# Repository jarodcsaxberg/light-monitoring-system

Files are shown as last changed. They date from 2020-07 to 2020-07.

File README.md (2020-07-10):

# Light Monitoring System

This project seeks to design a light sensor that can be placed in the Hoosier National Forest for a prolonged period of time. The sensor will collect data on the light conditions during the night to obtain an official designation from the International Dark Sky Association (ISDA) for the Hoosier National Forest. The designation is important to attract more visitors to the Forest, to create community-involved programs regarding data collection from the sensors, and to teach people about what the IDSA association strives to do and why it is important.

## Project Code

The code can be found in [project/](https://github.com/jarodcsaxberg/light-monitoring-system/tree/master/project), with the custom written code found in [project/Inc](https://github.com/jarodcsaxberg/light-monitoring-system/tree/master/project/Inc) and [project/Src](https://github.com/jarodcsaxberg/light-monitoring-system/tree/master/project/Src).

## Design

The KiCad files for the PCB design can be found in [kicad_proj/e314_light_sensor](https://github.com/jarodcsaxberg/light-monitoring-system/tree/master/kicad_proj/e314_light_sensor).

A KiCad schematic is located [here](https://github.com/jarodcsaxberg/light-monitoring-system/blob/master/design_analysis/schematic.pdf).

The Fusion 360 files for the enclosure design can be found in [enclosure/](https://github.com/jarodcsaxberg/light-monitoring-system/tree/master/enclosure).

## Analysis

Cost and power analysis for the project is located in [cost_power_analysis/](https://github.com/jarodcsaxberg/light-monitoring-system/tree/master/cost_power_analysis).

Design analysis can be found in [design_analysis/](https://github.com/jarodcsaxberg/light-monitoring-system/tree/master/design_analysis).

## Final Report

The final report can be found in [final_report/](https://github.com/jarodcsaxberg/light-monitoring-system/tree/master/final_report).

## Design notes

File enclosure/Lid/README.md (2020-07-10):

# Lab 9 - Lid
Completed in Fusion 360. Included dxf file for laser cutting.

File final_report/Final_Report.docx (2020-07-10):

Indiana University Engineering

Final Document

Team: Jarod Saxberg, Tyler Zhang

Project: Light Monitoring System

Date: 5/4/2020

# 1 Table of Contents

# 2 System Executive Summary

## 2.1 Description of the Community Partner

The project partner for this project is the Hoosier National Forest. The Hoosier National Forest’s goal is to achieve Dark Skies designation from the International Dark Skies Association (IDA) for its land before the next solar eclipse in 2024. Should they gain this designation, the Hoosier National Forest will benefit immensely from increased eco-tourism. Additionally, the data collected for the project will benefit wildlife and scientists that need the dark sky. The Hoosier National Forest will be the first to receive the project deliverables.

## 2.2 Stakeholders

If the project is particularly successful, the IDA may also use our project to assist assigning Dark Sky designation in other locations. Additionally, Professor Himebaugh is significantly interested in the project’s success, as he is concurrently working on similar projects for his research.

## 2.3 Project Objectives

The current method of collecting light data is by sending a ranger out with a handheld light sensor and manually collecting light data. Collecting light data is labor-intensive and costly, and as a result light data is collected infrequently. Our project aims to provide light data every five minutes, which will provide significant improvement over the current light data collection system. Precise light data is a direct requirement for Dark Sky designation, and the data from our project will be used by the IDA to consider Hoosier National Forest for a Dark Skies designation. Additionally, more frequent light data will allow the Hoosier National Forest to study the impact of dark skies on the wildlife.

## 2.4 Outcomes/Deliverables

Our goal is to produce a light monitoring system that improves upon the current light data collection system. Our system will be automated and can collect data more frequently because it will be deployed in the forest. Additionally, we will improve the current prototypes of the light monitoring system with a combination of more efficient code and better hardware. When the project is complete, we hope to leave behind light data and an improved prototype for the system.

# 3 System Description

This project seeks to design a light sensor that can be laid in the Hoosier National Forest for a prolonged period of time. The sensor will collect data on the light conditions during the night in an attempt to obtain a designation from the International Dark Sky Association. The designation is important to attract more people to the Forest, to create community-involved programs regarding data collection from the sensors, and to teach people about what the IDSA association strives to do and why it is important.

The light sensor is designed by taking many different considerations into account. These considerations involve safety, cost, and ethics, and they are all described in more detail later in the document. The software is designed with the help of CubeMX, which provides an extremely helpful starting point for the coding of each feature and includes utilities that help establish timers and explore various power consumption modes. The hardware was designed with KiCad, a user-friendly way to design schematics and pcb layouts. KiCad allows the user to have full control over the lithography of the resulting pcb, and performs electrical rules checking in the schematic to reassure the user that all connections are established. Creating a pcb with KiCad gives the designers more control over the board rather than purchasing a prebuilt board which could have features that are not necessary. More detailed descriptions of the software and hardware design are immediately following this section.

# 4 Software Design

## 4.1 High Level Block Design

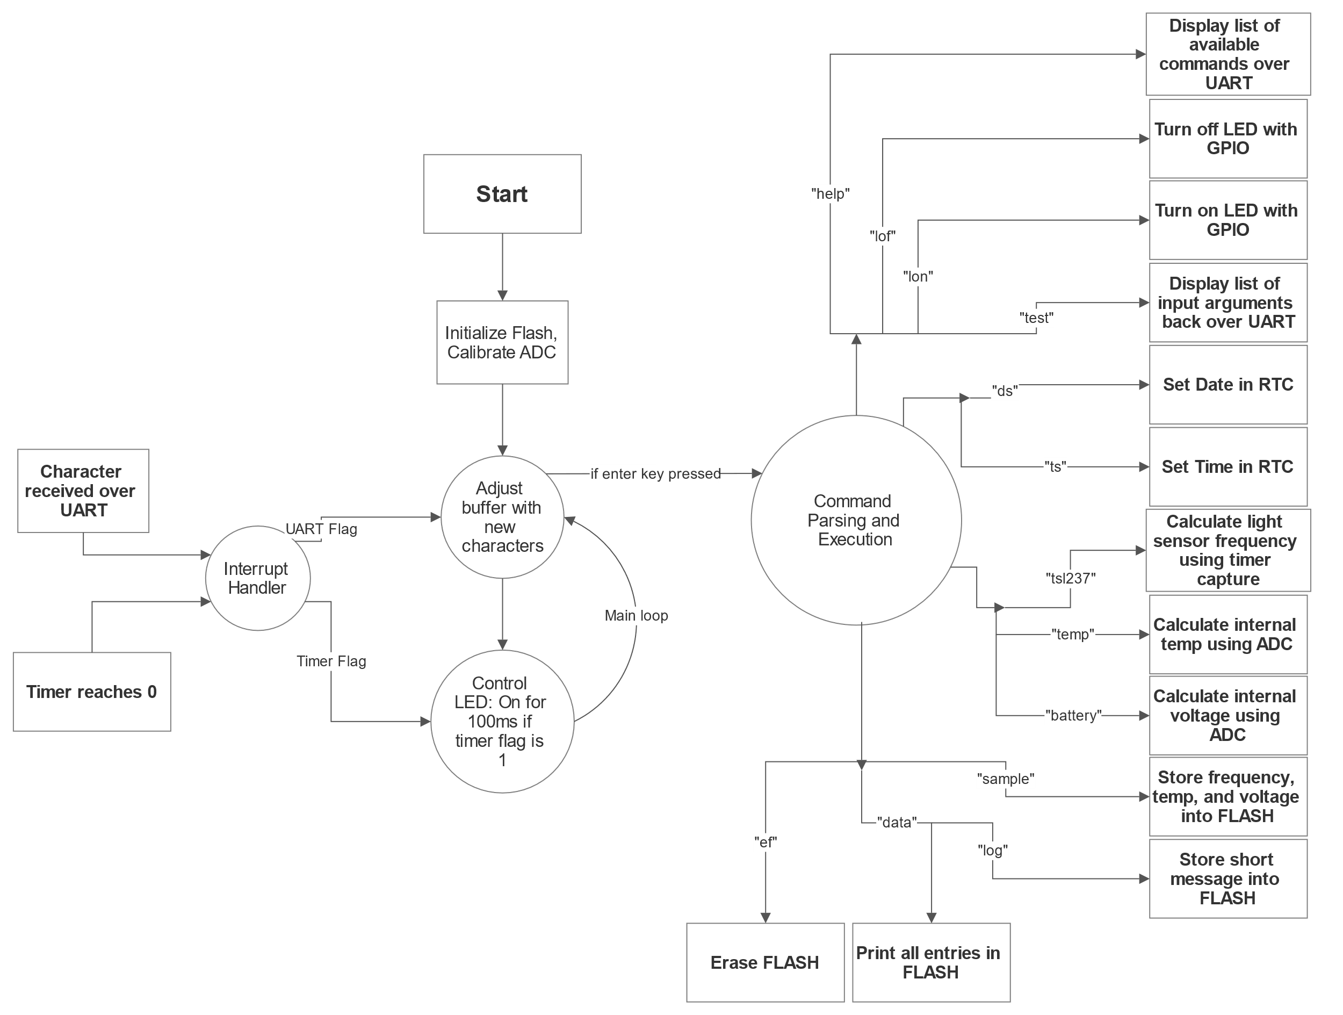
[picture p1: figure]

Figure 1: Software block design

Figure 1 shows the flow of our code. The code is mainly event-driven since the main loop waits for input over UART or for the timer to reach 0. Receiving characters over UART modifies an internal buffer, and if the enter key is detected, the system will perform a command. If the connected timer reaches 0, the code will tell an LED to blink on for 100ms. This behavior will eventually be replaced by storing a light sensor reading to flash memory.

## 4.2 Power Management and Modeling

The STM provides several run and low-power modes, each with different features and power consumption. Our goal is to leave the system in the field while requiring as little maintenance as possible. The system is designed to take light samples every 15 minutes for 12 hours a day, with each sample taking up to 15 seconds. When the system is taking a light sample, the STM will be in one of three running modes, and while it is idle, the system will be in one of seven low-power modes.

The following graphs show the power consumption of three promising combinations of run and low-power modes, generated by CubeMX. The rest of the combinations were tested in our full power analysis, which can be located here (https://github.iu.edu/jsaxberg/ES-SPRING-2020/blob/master/Lab10/e314_power_analysis_final.pdf). We are trying to determine the pair of run and low-power modes that will yield the best battery life estimation with a CR2032 battery.

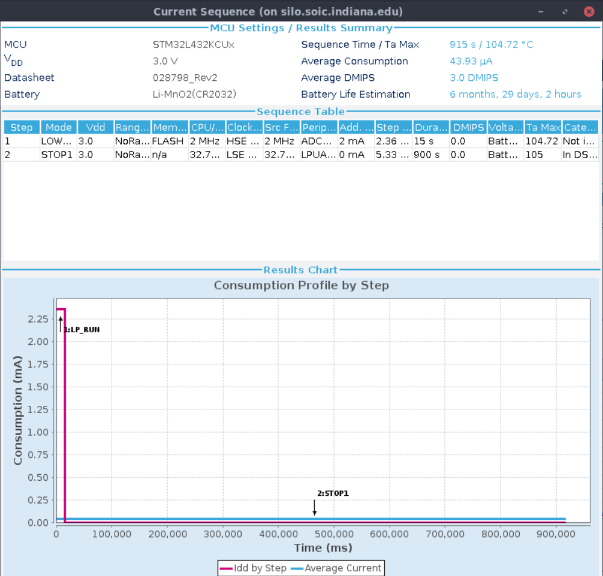
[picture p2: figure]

Figure 2: LPRUN with STOP 1

With these settings, battery life is at nearly 7 months and its wakeup time is 4 us. The LPUART and RTC can still be enabled, and SRAM is retained. These settings give us the best battery life estimation, but the LPRUN only allows the CPU to run at a maximum of 2 MHz, which may not be enough for the software.

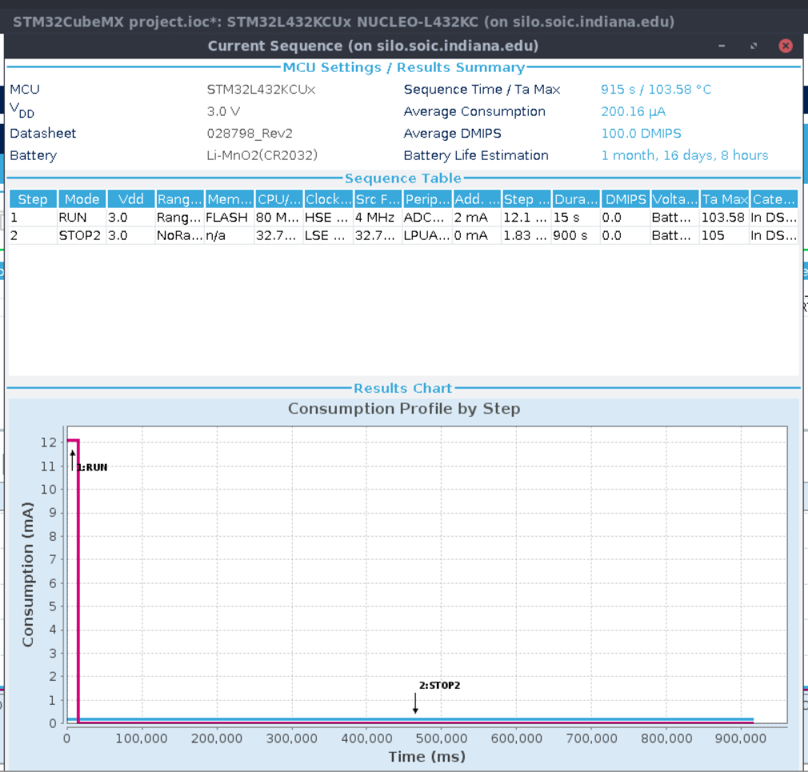
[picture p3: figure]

Figure 3: RUN1 with STOP 2

With these settings, battery life is at roughly 1.5 months and its wakeup time is 5 us. The LPUART and RTC can still be enabled, and SRAM is retained. However, RUN1 means the CPU is running at 80 MHz, which is unnecessary and draws significantly more power than LPRUN or RUN2.

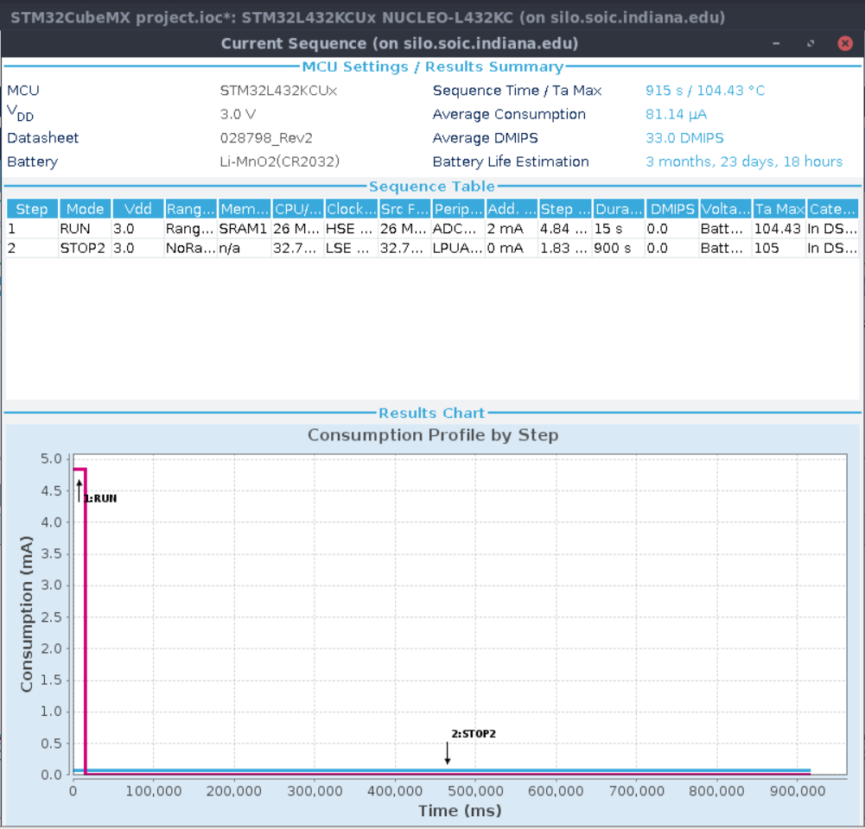
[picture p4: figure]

Figure 4: RUN2 with STOP 2

With these settings, battery life is at 3 months and 25 days and its wakeup time is 5 us. The LPUART and RTC can still be enabled, and SRAM is retained. RUN2 lets caps the CPU frequency at 26 MHz instead of 80 MHz, showing power consumption improvements.

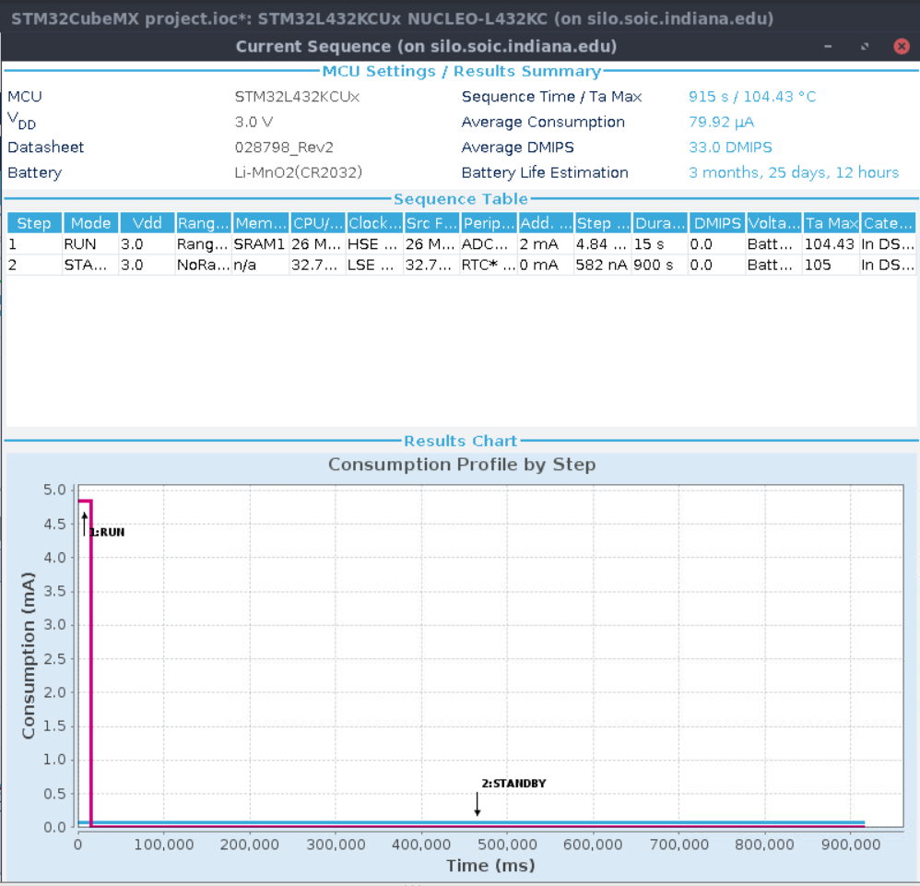
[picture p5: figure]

Figure 5: RUN2 with STANDBY + 32KB SRAM

With these settings, battery life is at 3 months and 25 days and its wakeup time is quite high at 14 us. The LPUART can no longer stay enabled, but RTC is still active and SRAM is retained. This means if we want to communicate with the device over UART, we must wait for the 15 second window when the system is back in the run mode.

The power combination that provides the best battery life for the least detrimental effects is RUN2 with STOP 2. The CPU runs at a max of 26 MHz which should be plenty for our code. STOP 2 allows the LPUART to remain on, allowing us to communicate with the device without waiting. It also has decent battery life estimation at 3 months and 23 days.

# 5 Hardware Design

## 5.1 Overview

KiCad was used to create a schematic and pcb layout for the light sensor project. In the design of the hardware, we needed to account for all components included on the board and manage the lithography so everything connects how it should. The design we determined was the best is shown below.

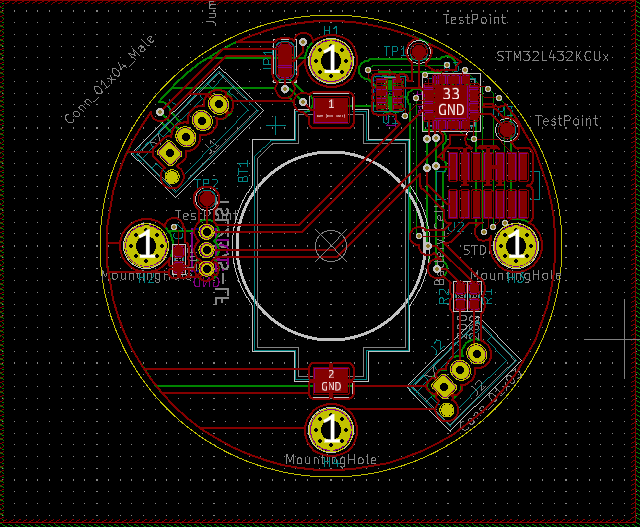
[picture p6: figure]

On the design, the red outlines represent lithography done on the top of the board, and the green represents the bottom. A more detailed explanation of certain important parts are included in the next section.

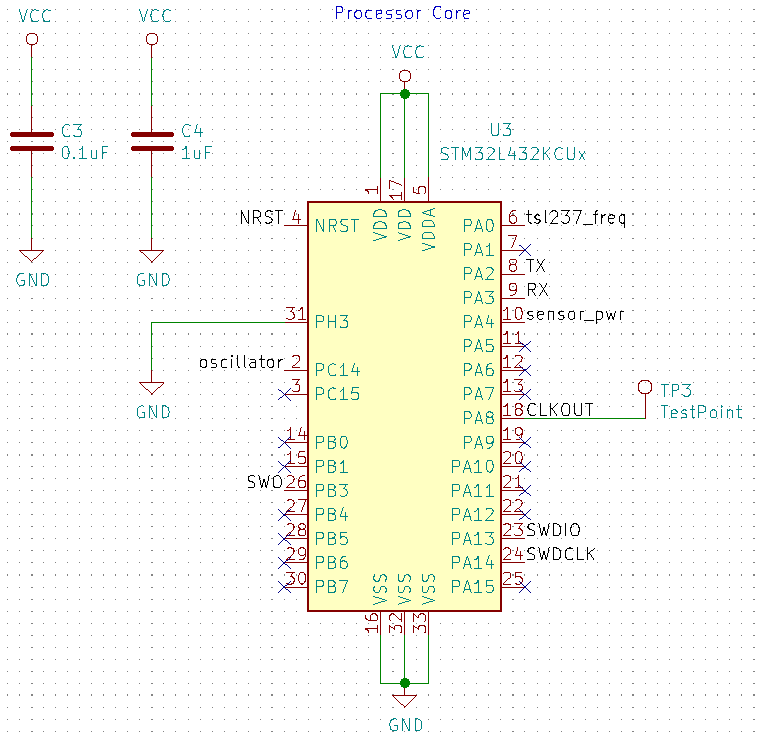
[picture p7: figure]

## 5.2 Processor Core

The processor used in the hardware is the STM32L432. This was chosen for its extensive number of timers and general support for the goals of this project. It is only somewhat limited in flash space, as there are other processors out there that have twice the storage space. The test point is to watch the system clock to use in reference with the other test points.

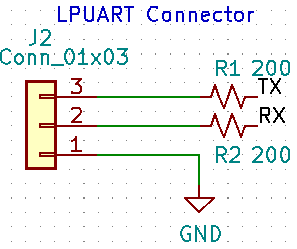
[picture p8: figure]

## 5.3 LPUART Connector

The LPUART connector is important as it allows for data to be received from the flash memory of the processor.

## 5.4 Light Sensor

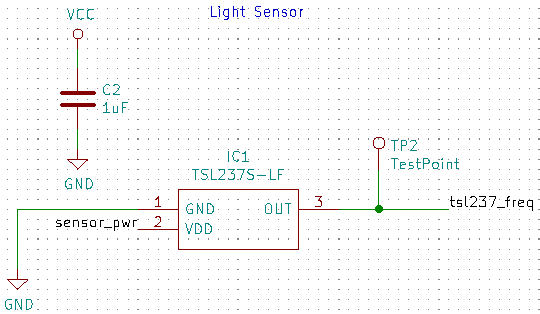
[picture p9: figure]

The light sensor is arguably the most important part of this project, as it is the key feature of it. The TSL237S light sensor was picked for the project, and the values it outputs from its readings are in terms of Hz which are processed in the software. The test point is to probe the output frequency.

## 5.5 Oscillator

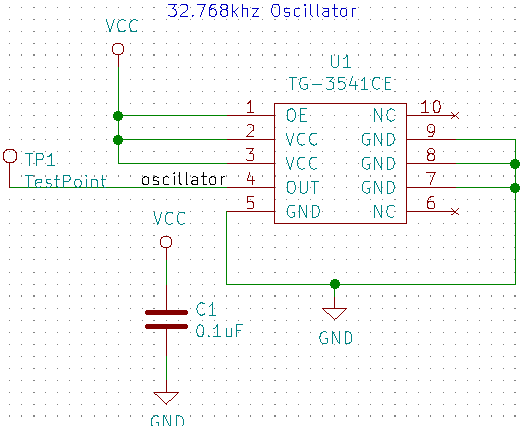
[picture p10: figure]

The oscillator is used to control the clock of the system. The test point is useful to see that the system is oscillating correctly.

# 6 Enclosure Design

## 6.1 Description of the Enclosure Design

The enclosure for our PCB is designed to be durable and protect the electronics from moisture. The figures below show the 3D models for our base and lid. The base will be 3D printed and the lid will be laser-cut from acrylic.

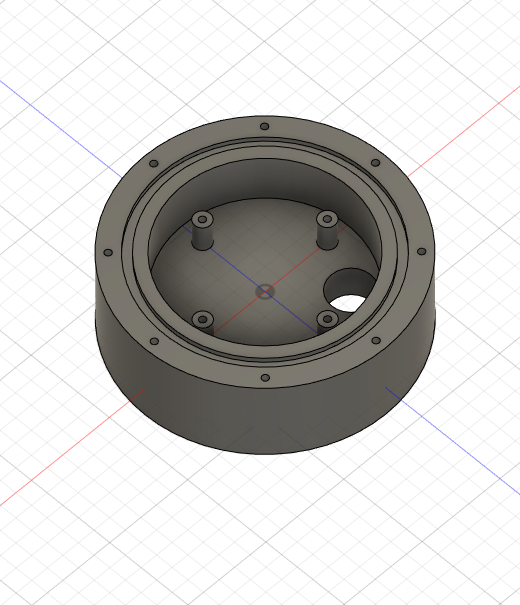
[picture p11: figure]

Figure 6: Base design, modeled in Autodesk Fusion

The base has standoffs to mount the PCB, and screw holes to secure the lid. The standoffs provide space between the PCB and the bottom of the base for the battery holder. The space can be used to store desiccant beads to reduce moisture in the enclosure. A cutout at the bottom of the base provides easy access to the LPUART connector, and will be filled in with a rubber plug.

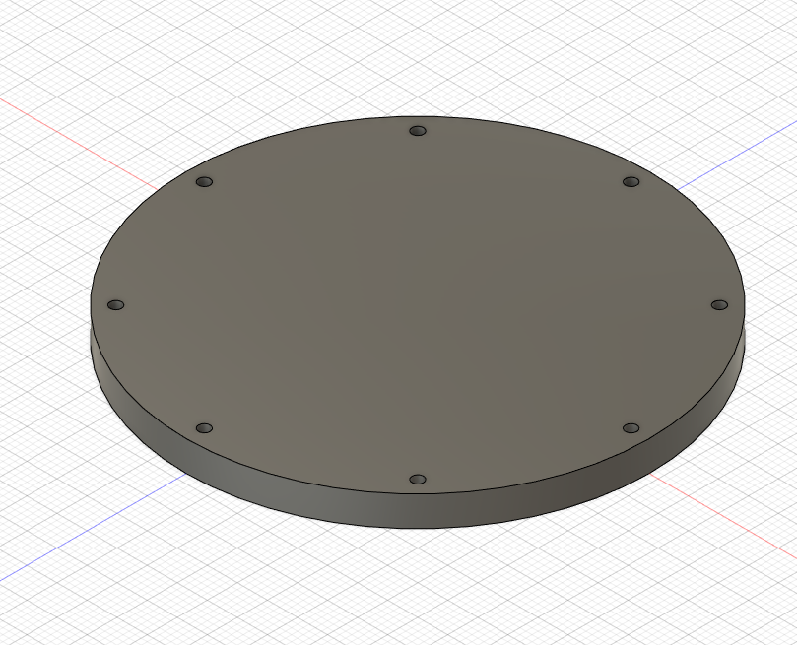
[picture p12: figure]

Figure 7: Lid design, modeled in Autodesk Fusion

The light sensor will be facing outwards, so the lid must be laser cut from clear acrylic to maintain accurate light readings. Between the lid and the base, there is a groove for the placement of a rubber O-ring to seal the enclosure.

## 6.2 NEMA Enclosure Level

The National Electrical Manufacturers Association provides standards for enclosures in indoor and outdoor locations. For our light monitoring system, our environment will be the Hoosier National Forest, which is considered an outdoor nonhazardous location. The following figure shows the NEMA classification levels for an enclosure in such an environment.

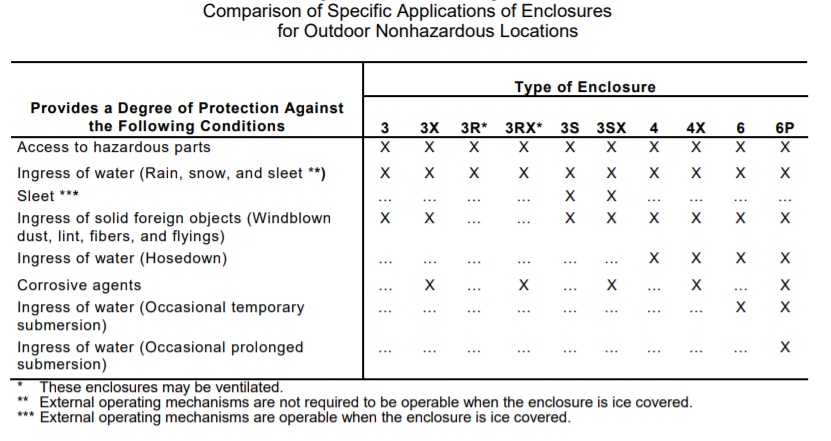
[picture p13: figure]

Figure 8: NEMA classification for enclosures in outdoor nonhazardous locations

All the electronics are secured inside the enclosure, so access to hazardous parts is limited. The design protects the electronics from windblown dust, lint, fibers, and flyings. Additionally, with the O-ring seal and the rubber plug, the electronics are protected against ingress of water from rain, snow, and sleet. Ice formation may shut down the electronics, but the enclosure will be intact, and the screws may still be removed. The enclosure is not well-sealed enough to protect against hose downs or any type of submersion. Additionally, corrosive agents may interact negatively with the acrylic and ABS material in our enclosure. With these degrees of protection, the classification of our enclosure type matches Type 3S.

# 7 System Cost Modeling

Background

For the design, we made sure to account for all mounting necessary. The four holes inside are ready for screws that mount the PCB to the base. The base will be 3D printed with a basic plastic material. It does not have to be anything more as plastic will last a while in basic outdoors conditions. The lid will be laser cut from clear acrylic. It must be clear to allow light through for the light sensor. All of the smaller holes in the lid and base are used for connecting the two and including some type of material to seal the two together, whether it be an o-ring or some type of glue. The PCB layout is the same layout that was designed in Lab 8.

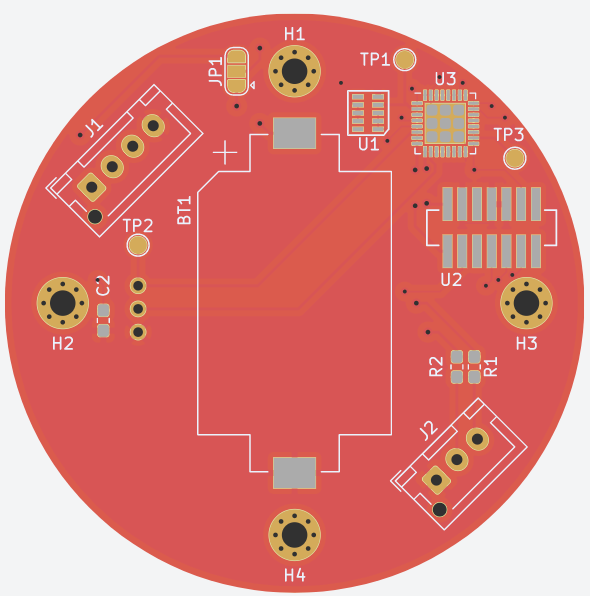
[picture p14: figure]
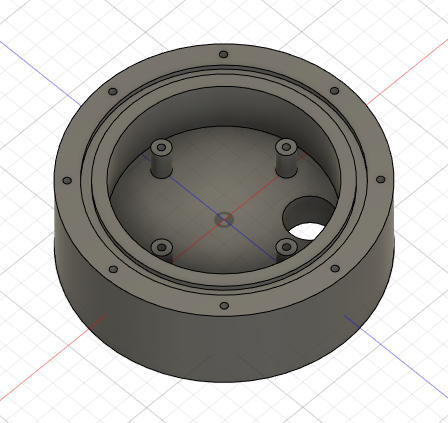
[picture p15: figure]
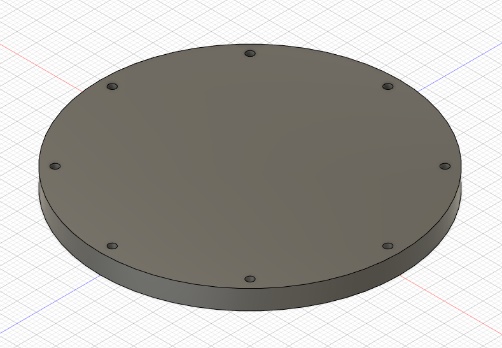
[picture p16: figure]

Cost Analysis

Sculpteo

| 5 | 20 | 50 | 100
Base | $355.60 | $1,890.00 | $4,725.00 | $9,450.00
Lid | $14.35 | $40.00 | $92.50 | $180.00
Total | $369.95 | $1,930.00 | $4,817.50 | $9,630.00

Shapeways (not including 15% edu discount) (prices for 3D printing only)

| 5 | 20 | 50 | 100
Base | $251.95 | $1,007.80 | $2,519.50 | $5,039.00
Lid | $78.90 | $315.60 | $789.00 | $1,578.00
Total | $330.85 | $1,323.40 | $3,308.50 | $6,617.00

Macrofab

| 5 | 20 | 50 | 100
PCB | $143.77 | $532.55 | $834.45 | $1,092.39

The above tables show prices to obtain each part from the different companies that offer 3D printing, laser cutting, and PCB printing services. For each company, I chose the most cost-effective solution which involved prioritizing cost over speed. For most of the companies, it would take around 2-4 weeks to receive the components ordered. Speed is not as important of a factor when we are trying to make sure the boards are as low-priced as possible.

Conclusion

Based on the various prices, the best and cheapest way to obtain the base + lid combo would be to use Sculpteo for the lid, Shapeways for the base, and Macrofab for the PCB. The price for Shapeways would also be reduced by taking advantage of the 15% education discount, which was not included in the above graphs. Adding this sum up, with the education discount included, the total for 100 light sensors would be $5,555.54; thus, the price per unit would be $55.55.

# 8 Safety Considerations

This section is a consideration of various possible failure modes and their effects on the system and its environment.

- Obstruction of acrylic lid

Any obstruction such as leaves or debris that block the acrylic lid of the enclosure will also block the light sensor, making sensor readings useless. This will likely be a very common occurrence, especially in the fall. Unfortunately, without any mechanism to clear debris, the device will be stuck in this state until a human or some entity clears away the obstruction.

To detect obstructions, we may add some code to check whether our light sensor data makes sense at the given time. For instance, if the system detects darkness during the middle of the day, it could log that an obstruction has been detected, and we can program the system to stop collecting data to preserve battery life.

- Battery reaches end of life prematurely

The battery life might be exhausted earlier than predicted due to battery manufacturing errors. Another possibility is that we accidentally programmed the system to stay in running mode instead of switching to low power while idle. When the battery dies, the only rescue is for a human to load the data logs from FLASH and reset the device, since losing battery power prevents the system from logging any more data. However, since our logs should display battery voltage with a timestamp, we can figure out at what time we lost power and attempt to debug our issue.

- Defective battery connection (short)

If the battery holder is defective, it may create a short circuit between the leads of the battery. This is quite dangerous as the battery will heat up and potentially cause a small explosion. If this happens inside the enclosure, the hazard will be isolated and will damage the electronics. The coating on the PCB will prevent any fires from starting. However, it is very likely that the short would be caught before the PCB even makes it into the enclosure, because the process happens very quickly once the battery is in place. This failure mode would endanger anyone nearby as well as damage the other electronics on the PCB.

- Faulty peripherals

Faulty peripherals on the STM such as the ADC or the RTC or problems with the TSL237 will make the data collected useless. We would need to replace the microcontroller or sensor. Fortunately, this is usually caught by quality assurance during manufacturing, so it is unlikely to become our issue. Additionally, if it happens, it is easy enough to check that the peripherals are working before deploying the system.

- Rubber plug comes loose

In our enclosure design, there is a removable rubber plug on the bottom of the base that allows us to access the UART connector. If this plug is loose or removed, it will expose the electronics to the environment, and may allow moisture or water to get inside. Moisture could potentially short or damage the electronics and ruin the collected data. Additionally, if for any reason a fire starts inside the enclosure, the fire will be exposed to the forest if the rubber plug is missing. We must make sure that the plug is properly sealing the hole before deploying the system.

- Extreme temperature conditions

With our device outdoors, the system is at the mercy of the elements. The STM and TSL237 function at a relatively wide range of temperatures, but at the extremes, unpredictable behavior can occur. At extremely low temperatures, the battery will not be able to generate enough current, which may shut off the RTC, making future timestamps inaccurate. At extremely high temperatures, the battery will overheat and may catch fire. We must be sure the Hoosier National Forest has temperature ranges that fall within the operating temperature range of our system.

- Tampering from tourists

Tourists may be curious about the device if spotted in the forest. They may try to examine the electronics by opening the interior or steal the device. This may affect data quality or cause damage if handled improperly. The closer we deploy the device to a well-travelled path, the more likely we will encounter tourists. We can potentially reduce tampering by letting visitors know what the devices are doing so they do not interfere.

# 9 Ethical Considerations

This section will detail all the various ethical considerations that were considered over the course of the project.

- Mounting the sensor to the ground

The grounds of the Hoosier National Forest are protected, and due to these protections, no stakes can be inserted into the ground. To account for this, we must have some way of weighing the sensors down, so they do not get moved by wind or animals. There is only so much we can do to account for this, and the best way to do so is to add some weight to the bottom of the enclosure.

- Damage to animal and insect ecosystems

The light sensor could possibly interfere with insects on the ground. We attempt to reduce this impact by placing the sensors far apart from one another and keeping the radius of the sensor and enclosure small.

- Potential hazardous waste if the sensors are forgotten

If the light sensors are damaged or moved, it may be difficult to retrieve them from the Forest. The forgotten sensors would be left in the Forest until they happen to be found, or they decompose. The sensors are plastic and metal, both of which take a while to decompose. The battery of the system and the components on the pcb also have toxic materials within them, and they have the potential to release these into the environment. We mitigate this by noting the locations of all the sensors when they are planted and including some form of camouflage to the design to reduce the chance they are found by external people or animals.

- Increased park traffic will negatively affect the animals

If the project goes to plan, part of it is trying to attract more people to the Forest. This could negatively affect the natural life there and impact animal habitats. We believe that the increased awareness that this project will bring is of greater importance. The Forest is very large and widespread. An increase of people at the park will not have as great of an effect on the overall park, and while they are there, they will learn about the Dark Sky endeavor and why it is done. This has the potential to affect life outside the park too. If someone learns about the initiative at the park, then goes home and changes their driveway light to a Dark Sky recommended light, it will benefit more than just the park. These people also have the potential to spread the information through work of mouth, further increasing the affect of the community involvement project.

# 10 Future Work

There are several ways to improve the light monitoring system, both in terms of design and software.

## 10.1 Improvements to Software

Currently the software in our system is run in “bare-metal” (i.e. tasks execute one at a time and not concurrently). One improvement is to utilize a real-time operating system (RTOS) to gain access to multiple threads and run tasks concurrently. This would be beneficial for tasks that require any sort of polling, such as calculating frequency, which currently is done by polling an input capture timer for two readings. During that time, the main loop is stopped, which could potentially be long enough to miss important interrupts from UART or other timers. The function printf also has similar behavior, as it calls a function called putchar that also waits for the UART module to receive before returning. Placing command execution and interrupt processing into separate threads or tasks with an RTOS will make the code more robust.

## 10.2 Improvements to Hardware

The light monitoring system currently runs on a button battery, but a possible improvement to extend battery life is to add a solar cell to the system. The solar cell could charge a capacitor during the day and the system could use the capacitor as well as a backup battery during the night to record data. Solar power could make the system sustainable and reduce the number of times we need to replace the battery.

Another addition would be providing adding a Bluetooth module to the system to let users download data from the system without needing to connect with UART. Not only is this more convenient, but also it allows us to take advantage of citizen science by allowing visitors at the Hoosier National Forest collect data for us. We could build an app for visitors to download and let them use the Bluetooth receivers in their phones to retrieve data from our systems. The app could then send us the data when the phone connects to the internet. This would greatly improve the efficiency of data collection for the Hoosier National Forest.

# 11 Team

## 11.1 Team Members

### 11.1.1 Jarod Saxberg

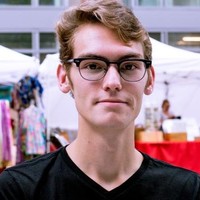
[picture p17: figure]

Jarod is a junior at Indiana University pursuing a major in Intelligent Systems Engineering concentrating in Computer Engineering, and two minors in Mathematics and French. He will be working over the summer of 2020 as a security software engineering intern and plans to either continue with a career in cyber security, or work at the intersection of hardware and software.

### 11.1.2 Tyler Zhang

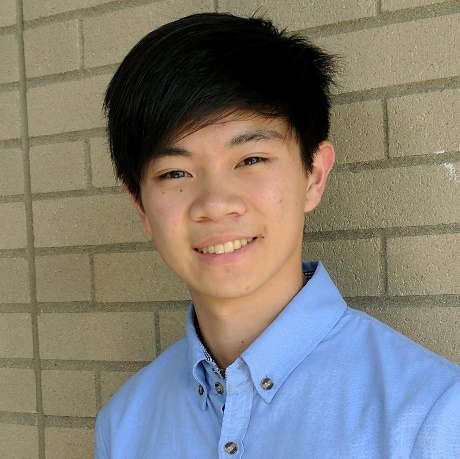
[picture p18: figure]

Tyler is a student at Indiana University pursuing a double degree in Mathematics and Intelligent Systems Engineering, with a concentration in Cyber-Physical Systems. Future career goals include obtaining a master’s degree in engineering and working in the field of embedded systems.

## 11.2 Workload

Both individuals contributed significantly to the design and documentation of the project, including the code, the PCB layout, and the enclosure model. The following is the breakdown of specific contributions.

### 11.2.1 Jarod Saxberg

- Both members worked extensively on the code, and focused on the software more than the hardware. One of them would usually get a good start on the code for a lab, then they would get together and work out any bugs and/or finish work that was not started yet. Most progress was made while working together.
- Jarod designed a PCB layout and enclosure model, along with Tyler creating his own too.
- Jarod completed the system cost analysis and was responsible for the odd-numbered sections of the final report. The Bill of Materials was split in half with each member working on their half.

### 11.2.2 Tyler Zhang

- Both individuals contributed significantly to the code. Typically, Tyler would provide a strong starting point for the labs by laying out the framework and structure, setting up functions, creating new files, and experimenting with how best to interact with the hardware and peripherals.
- Tyler designed his own PCB layout and enclosure model, as did Jarod.
- In terms of documentation, Tyler completed the power analysis and is responsible for the even-numbered sections in the final report. Both individuals picked parts for the bill of materials.

# 12 References

- NEMA Enclosure Types, NEMA 250-2013, Nov. 2005. [Online]. Available: https://www.nema.org/Products/Documents/nema-enclosure-types.pdf
- International Dark Sky Places, IDA [Online]. Available: https://www.darksky.org/our-work/conservation/idsp/

Last revised 05/04/2020 15

Final Document Team: Jarod & Tyler, Project: Light Monitoring System

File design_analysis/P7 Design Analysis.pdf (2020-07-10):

Saxberg and Zhang 1

Design Analysis

Summary:
We consider three microcontroller alternatives to the STM32L432KC (STM). The first is the MSP430F5359, which boasts efficient low-power modes and access to more memory and GPIO pins. The second is the ADuCM4050, which includes more memory and some security features. The third is the MAX32625, which has access to more memory, an extremely low power mode, and faster clock speed.

Alternative 1:
MSP430F5359 (http://www.ti.com/product/MSP430F5359)
http://www.ti.com/lit/ds/symlink/msp430f5359.pdf
The MSP430F5359 (MSP) is a low-power MCU from Texas Instruments, with specifications that are comparable with the STM. The operating voltage for the MSP falls between 1.8V and 3.6V, which is similar to that of the STM. Both chips have dedicated 32 kHz oscillators for the RTC, a 12-bit ADC channel, access to general-purpose timers, and UART support. Both chips utilize a similar amount of SRAM, with the MSP using 66 kB while the STM uses 64 kB.
A benefit of using the MSP is that it has multiple efficient low-power modes, with most of its low-power modes consuming less than 4 uA of current per MHz. The only time the STM achieves this type of power efficiency is when it is in one of its stop modes. The MSP also has 74 GPIO pins compared to the STM’s 26 pins, 64 priority levels for its interrupt handler compared to STM’s 16 levels, and 512 kB of flash memory compared to the STM’s 256 kB. Although the MSP seems to have higher specifications than the MSP, in practice we do not need the additional GPIO pins, priority levels, and flash, since we do not use all of the ones available on the STM.
A significant drawback is that the MSP uses a 16-bit RISC core instead of a 32-bit ARM core. As a result, it will be tough to implement floating-point operations, but it does have dedicated hardware for 32-bit integer operations. For 1000 units, the MSP is also more expensive, as it costs around $4.50 for the MSP on the Texas Instruments website. The STM only costs $2.43 from Digikey.

Alternative 2:
ADuCM4050 (https://www.analog.com/en/products/aducm4050.html)
https://www.analog.com/media/en/technical-documentation/data-sheets/ADuCM4050.pdf
The ADuCM4050 is an ARM Cortex-M4F based microcontroller from Analog Devices. The specifications are similar to the STM, but there are a few differences that make it better in some regards, and worse in others. Both chips have similar power supply voltages, 1.74V-3.6V for the ADuCM and 1.71V-3.6V for the STM. They also both have hibernate/sleep modes, which is necessary for our long term use of the light sensor. The clock in both chips is controlled by a 32 kHz crystal oscillator clock. The temperature range for both microcontrollers is similar, -40C to 85C, however the data sheet for the STM says the upper range can be 85/105/125C.

Saxberg and Zhang 2

The ADuCM chip only has three general purpose timers compared to the STM chip’s 11 varied timers. It also lacks in communication interfaces, only having 7 serial communication ports compared to the STM’s 14. Cost-wise, the ADuCM chip is much more expensive, currently priced at $10.29 per unit when buying 1000+, whereas the STM retails for $2.43.
Some advantages of the ADuCM chip are detailed below. The flash memory size is much larger, 512 kB versus 256 kB. This would allow for more storage of light sensor data and less time spent having to retrieve the data. The ADuCM chip also has 72 pins compared to the STM’s 26. If necessary, the ADuCM chip also has a hardware cryptographic accelerator which supports 3 different types of cryptographic functions, which could be used to protect our data from anyone who may steal the chip while it is deployed.

Alternative 3:
MAX32625 (https://www.maximintegrated.com/en/products/microcontrollers/MAX32625.html)
https://datasheets.maximintegrated.com/en/ds/MAX32625-MAX32626.pdf
The MAX32625 is an ARM Cortex-M4 based microcontroller from Maxim Integrated that boasts some impressive specs, but for a slightly increased price. The power supply is a slightly tighter range than the STM’s, running between 1.8V-3.3V compared to 1.71V-3.6V.
This chip is very powerful in some regards. It has 512 kB for flash storage compared to the STM’s 256 kB, along with an 8 kB instruction cache to run operations more efficiently. The low power mode on this chip is extremely efficient, running at only 600 nA with the RTC enabled. There are also 40 pins available for GPIO purposes, which gives it a lot of versatility with different sensors; however, it is not as important of an advantage for this project. The chip also has built in support for various cryptographic functions, but again they are not as important. While this chip has some advantages, it also has disadvantages. There are only six 32-bit timers in the MAX chip compared to 11 in the STM chip, but since we don’t make use of all the timers in the STM chip, it is not that important of a downside. The biggest downside is the temperature range of the chip. The MAX chip only has a temperature range of -30C-85C compared to the STM’s temperature range of -40C-85C. The 10 degree difference on the lower bound is extremely important because Indiana winters can get colder than -30C. For long-term survivability, this is a big flaw of this microcontroller.

Conclusion:
Overall, the three chips described here all serve as good microcontrollers, but for the light sensor project the STM chip is the best choice. This is due to its low cost for the specs it has. It may lack flash storage space, but this is mitigated by an idealized increase of people at the forest using an app to help collect the data more often.

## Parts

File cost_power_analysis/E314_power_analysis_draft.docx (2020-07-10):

Power Analysis

Background:

Our light monitoring system is composed of the STM32L432KC (STM) microcontroller and the TSL237 light sensor. The system is designed to take light samples every 15 minutes for 12 hours a day, with each sample taking up to 15 seconds. When the system is taking a light sample, it will be in one of three running modes, and while it is idle, the system will be in one of seven low-power modes. The following graphs show the power consumption of different combinations of run and low-power modes, generated by CubeMX. We are trying to determine the pair of run and low-power modes that will yield the best battery life with a CR2032 battery.

When testing each of the running modes, we made sure to use the highest CPU frequency that each mode can handle. We enabled the ADC, RTC, UART, a timer, and several GPIO peripherals. Additionally, for each run mode, we gave an additional 2 mA of consumption to account for the light sensor. For the low power modes, we enabled only the RTC and the UART if it is supported. In each plot, we let the system run for 15 seconds and then enter low-power mode for 900 seconds (15 minutes).

Analysis

RUN (Range 1)

The following figures 1-6 show the power consumption of the RUN power mode at Range 1 with multiple low-power modes. In each case, the CPU is running at a max of 80 MHz. However, the faster clock speed means that the STM draws more power. The code is running from FLASH, so that also takes extra current to maintain. Figure 6 shows the longest battery life approximation with STANDBY as the low-power mode at 1 month, 16 days and 15 hours. The other run modes last much longer across the board. Performance-wise, we receive little benefit from the extra clock speed because our system does not compute much, it just stores data. Thus, it does not seem worth sacrificing battery life for the extra speed of RUN at Range 1.

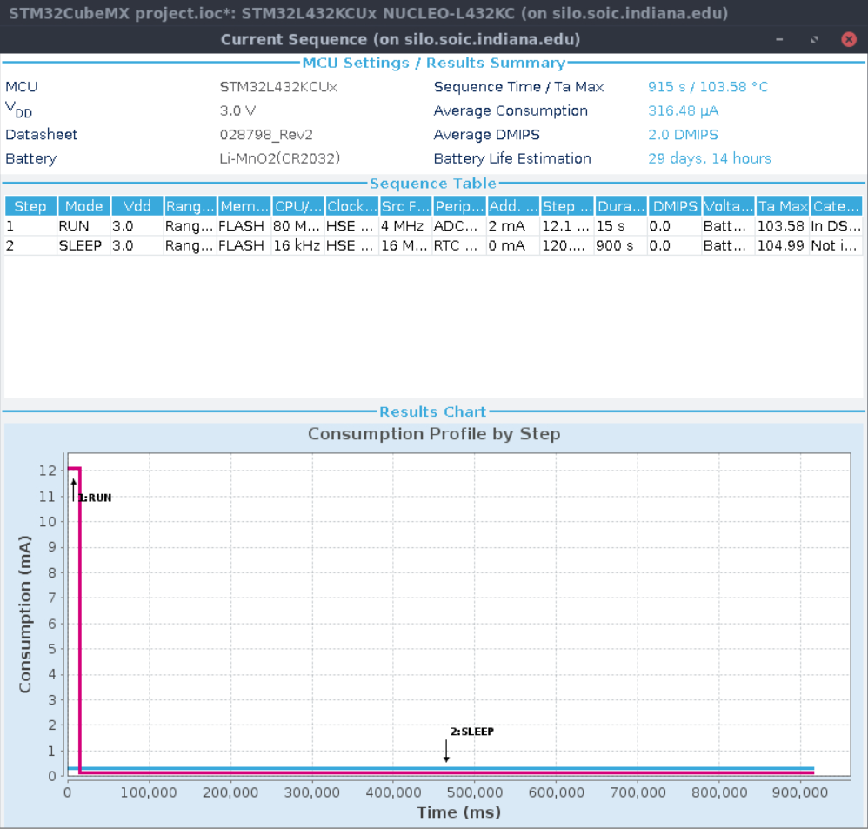
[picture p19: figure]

Figure 1: RUN (Range 1) with SLEEP

SLEEP consumes the most current out of all the low-power modes at 120 uA, but as a result the wake-up time is the fastest at 6 clock cycles. The LPUART and RTC can still be enabled, and SRAM is retained.

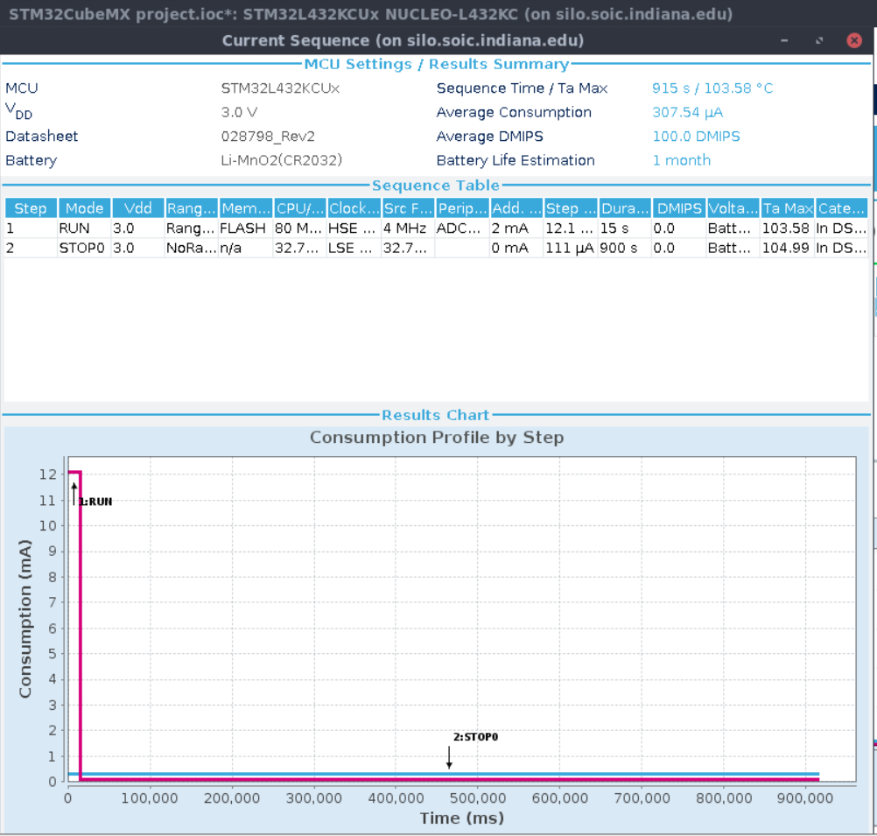
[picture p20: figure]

Figure 2: RUN (Range 1) with STOP 0

STOP 0 consumes slightly less current than SLEEP at 111 uA, and its wakeup time is slower at 0.7 us. The LPUART and RTC can still be enabled, and SRAM is retained. Battery life is improved by about 10 hours compared to using SLEEP.

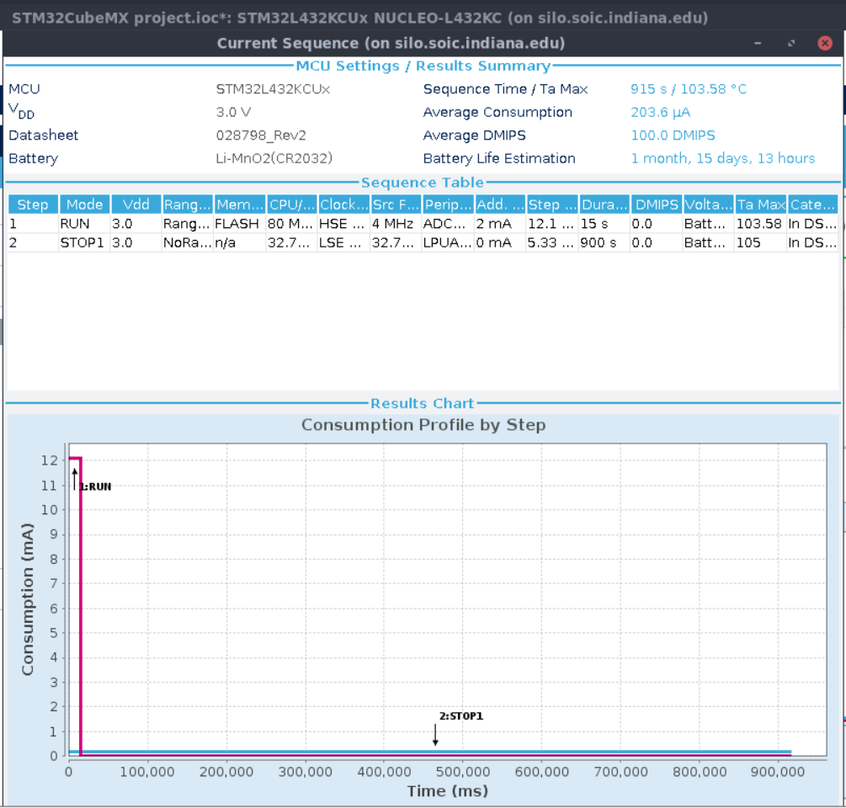
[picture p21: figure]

Figure 3: RUN (Range 1) with STOP 1

STOP 1 consumes even less current than STOP 0 at 5.3 uA, and its wakeup time is 4 us. The LPUART and RTC can still be enabled, and SRAM is retained. The difference between STOP 0 and STOP 1 in terms of power consumption is significant though, giving us an extra 15.5 days before the battery dies.


Figure 4: RUN (Range 1) with STOP 2

STOP 2 consumes less current than STOP 1 at 1.8 uA, and its wakeup time is 5 us. The LPUART and RTC can still be enabled, and SRAM is retained. STOP 2 gives us an additional 19 hours of battery life over STOP 1.

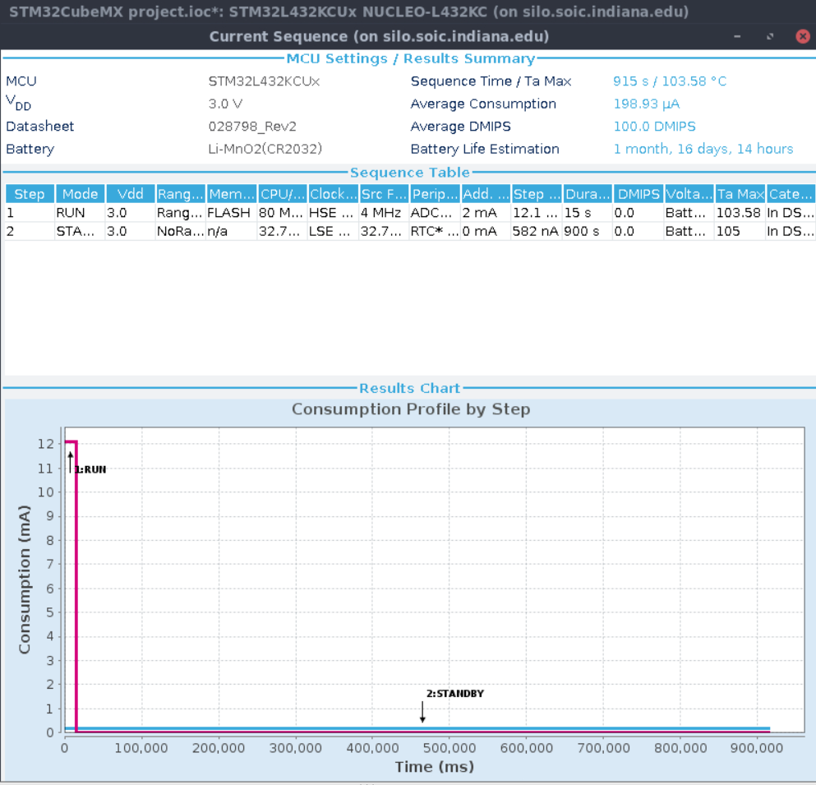
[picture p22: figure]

Figure 5: RUN (Range 1) with STANDBY + 32KB SRAM

STANDBY with SRAM consumes even less current than STOP 2 at 582 nA, but its wakeup time is more than doubled at 14 us. The LPUART can no longer stay enabled, but RTC is still active and SRAM is retained. This means if we want to communicate with the device over UART, we must wait 15 minutes before the system is back in the run mode. For the effort, we only gain 6 hours of extra battery life compared to STOP 2.

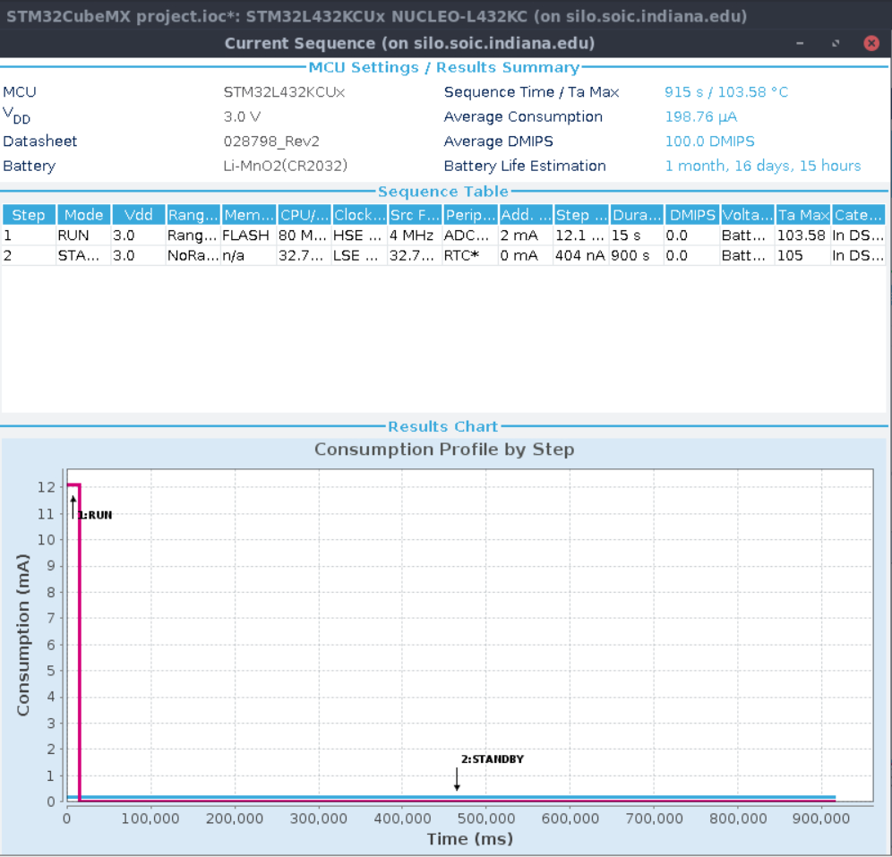
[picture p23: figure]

Figure 6: RUN (Range 1) with STANDBY

STANDBY without SRAM consumes less current than before at 404 nA, but its wakeup time is still at 14 us. The LPUART can no longer stay enabled and SRAM is not retained, but RTC is still active. This means if we want to communicate with the device over UART, we must wait 15 minutes before the system is back in the run mode. This only gains us 2 hours of battery life.

RUN (Range 2)

The following figures 7-12 show the power consumption of the RUN power mode at Range 2 with different low-power modes. Range 2 is different from Range 1 because the CPU can only run at a max of 26 MHz, and the code is executing from SRAM instead of FLASH. If the low-power mode does not retain SRAM, we will need to move our code to FLASH before entering. However, the benefit to the battery life for these drawbacks is significant. Figure 12 shows the longest battery life approximation with STANDBY as the low-power mode at 3 months, 25 days and 18 hours.

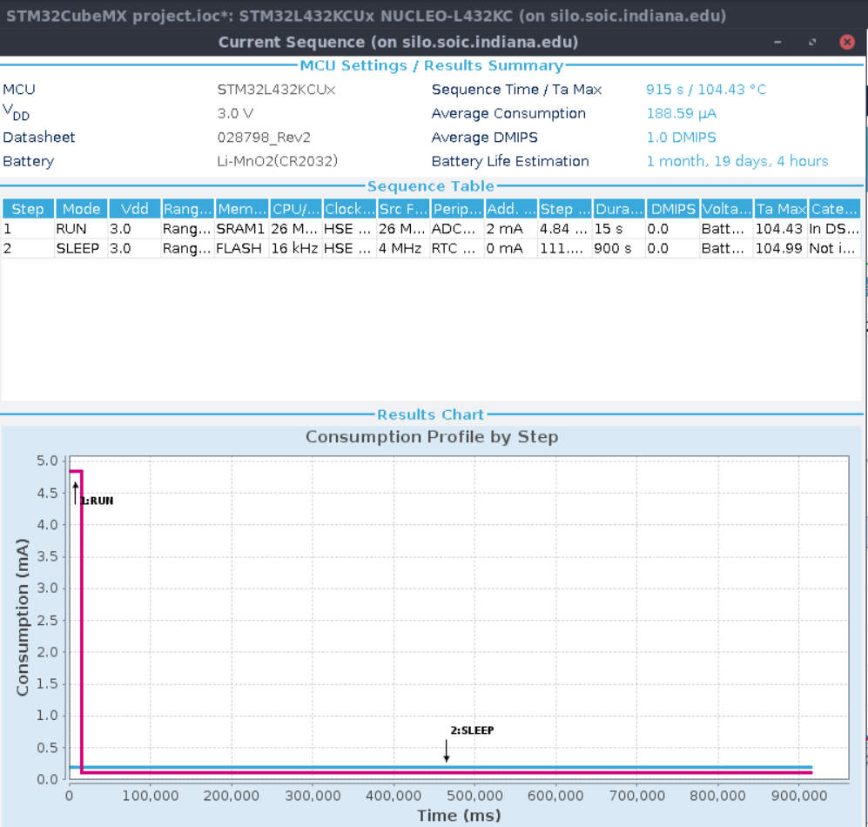
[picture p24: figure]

Figure 7: RUN (Range 2) with SLEEP

As mentioned before, SLEEP consumes the most current out of all the low-power modes at a little over 111 uA, but as a result the wake-up time is the fastest at 6 clock cycles. The LPUART and RTC can still be enabled, and SRAM is retained.

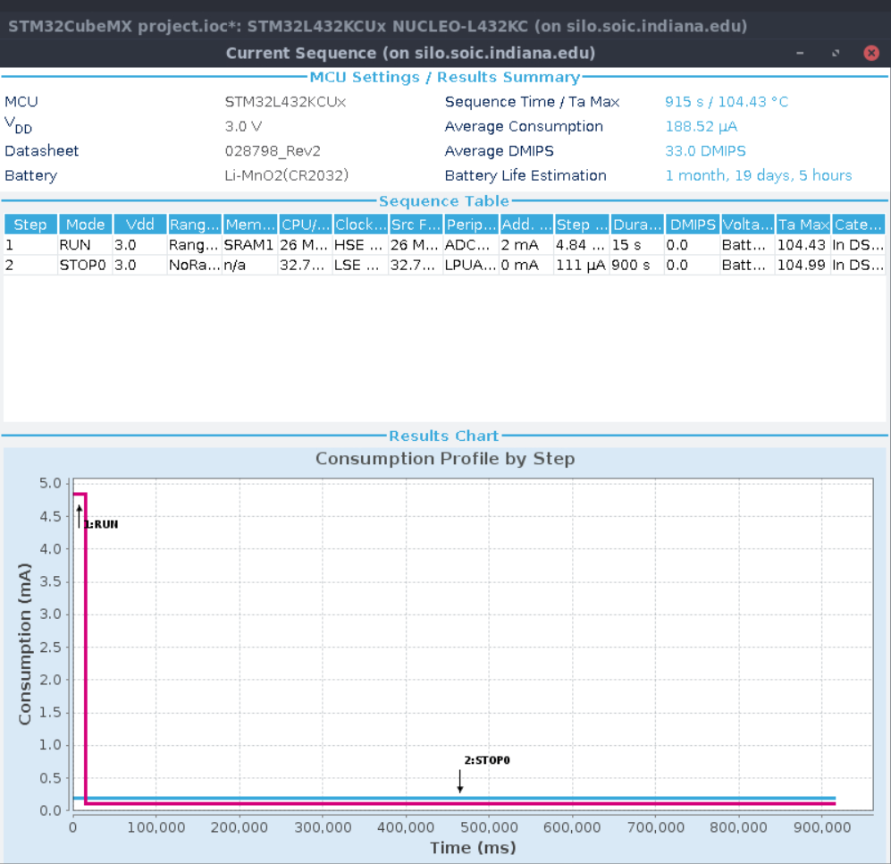
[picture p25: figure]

Figure 8: RUN (Range 2) with STOP 0

STOP 0 consumes roughly the same current as SLEEP at 111 uA, and its wakeup time is slower at 0.7 us. The LPUART and RTC can still be enabled, and SRAM is retained. Battery life is improved by about 1 hour compared to using SLEEP.

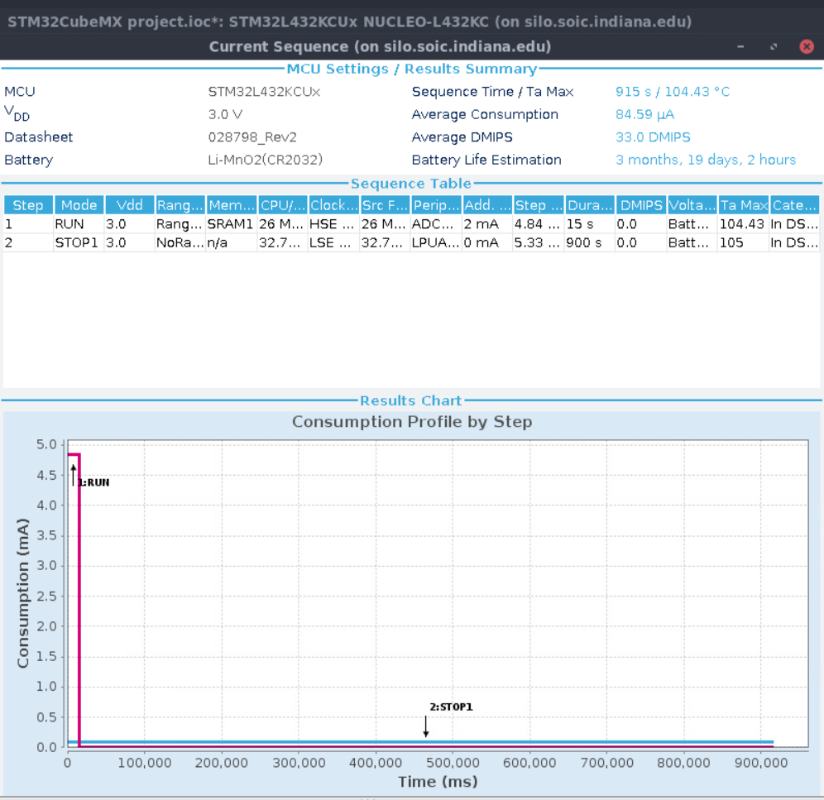
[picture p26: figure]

Figure 9: RUN (Range 2) with STOP 1

As mentioned before, STOP 1 consumes much less current than STOP 0 at 5.3 uA, and its wakeup time is 4 us. The LPUART and RTC can still be enabled, and SRAM is retained. The difference between STOP 0 and STOP 1 in terms of power consumption is significant though, giving us an extra 2 months before the battery dies.


Figure 10: RUN (Range 2) with STOP 2

As mentioned before, STOP 2 consumes less current than STOP 1 at 1.8 uA, and its wakeup time is 5 us. The LPUART and RTC can still be enabled, and SRAM is retained. STOP 2 gives us an additional 4 days and 16 hours of battery life over STOP 1.


Figure 11: RUN (Range 2) with STANDBY + 32KB SRAM

As mentioned before, STANDBY with SRAM consumes even less current than STOP 2 at 582 nA, but its wakeup time is more than doubled at 14 us. The LPUART can no longer stay enabled, but RTC is still active and SRAM is retained. This means if we want to communicate with the device over UART, we must wait 15 minutes before the system is back in the run mode. For the effort, we gain 1 day and 18 hours of extra battery life compared to STOP 2.


Figure 12: RUN (Range 2) with STANDBY

As mentioned before, STANDBY without SRAM consumes less current than before at 404 nA, but its wakeup time is still at 14 us. The LPUART can no longer stay enabled and SRAM is not retained, but RTC is still active. This means if we want to communicate with the device over UART, we must wait 15 minutes before the system is back in the run mode. Additionally, upon entering the state we must store the code in FLASH, and upon exiting we must load the code from FLASH into SRAM. This only gains us 6 hours of battery life.

LPRUN

The following figures 13-17 show the power consumption of the LPRUN power mode with different low-power modes. LPRUN has unique access to LPSLEEP, but it does not support STOP 2. The CPU can only run at a max of 2 MHz. The slower clock speed means that the STM conserves a lot of power. The code is running from FLASH, so that also takes extra current to maintain. However, the benefit to the battery life for this drawback is significant. Figure 17 shows the longest battery life approximation with STANDBY as the low-power mode at 7 months, 24 days and 15 hours. The issue will be whether 2 MHz is enough to perform all our operations in a reasonable amount of time.


Figure 13: LPRUN with LPSLEEP

LPSLEEP can only be used with LPRUN and consumes very little current at just 72 uA. It also wakes up from sleep very quickly at just 6 clock cycles. The LPUART and RTC can still be enabled, and SRAM is retained.


Figure 14: LPRUN with STOP 0

STOP 0 is surprisingly worse than LPSLEEP when combined with LPRUN, consuming 111 uA of current and with a slower wakeup time of 0.7 us. The LPUART and RTC can still be enabled, and SRAM is retained. Battery life is worse than LPSLEEP by 22 days; it is unlikely we would choose STOP 0 over LPSLEEP when using LPRUN.


Figure 15: LPRUN with STOP 1

As mentioned before, STOP 1 consumes much less current than STOP 0 at 5.3 uA, and its wakeup time is 4 us. The LPUART and RTC can still be enabled, and SRAM is retained. The difference between STOP 0 and STOP 1 in terms of power consumption is significant though, giving us almost 5 extra months before the battery dies.


Figure 16: LPRUN with STANDBY + 32KB SRAM

STANDBY with SRAM consumes even less current than STOP 1 at 582 nA, but its wakeup time is more than tripled at 14 us. The LPUART can no longer stay enabled, but RTC is still active and SRAM is retained. This means if we want to communicate with the device over UART, we must wait 15 minutes before the system is back in the run mode. For the effort, we gain about 24 days of extra battery life compared to STOP 1.


Figure 17: LPRUN with STANDBY

As mentioned before, STANDBY without SRAM consumes less current than before at 404 nA, but its wakeup time is still at 14 us. The LPUART can no longer stay enabled and SRAM is not retained, but RTC is still active. This means if we want to communicate with the device over UART, we must wait 15 minutes before the system is back in the run mode. This only gains us 1 day and 1 hour of battery life.

Conclusion

For the run mode, RUN at Range 2 provides a reasonable clock speed for decent battery performance. LPRUN would provide much better battery performance, but 2 MHz may be too slow for calculations and will make the response over UART slow. For the low-power mode, STOP 2 seems ideal because it provides the best battery performance while still allowing us to communicate over UART and retain the state of SRAM. STANDBY options would give us better battery life, but it disables UART, meaning that we only have a small 15 second window to connect with the system in the RUN state. As figure 10 states, the RUN (Range 2) coupled with STOP 2 gives 3 months, 23 days and 18 hours of battery life. Moreover, if we do not need the full 26 MHz for our computations, we could lower the clock rate to achieve even better battery life.

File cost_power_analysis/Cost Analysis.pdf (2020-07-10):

## Prototype Cost Estimation

### Background

For the design, we made sure to account for all mounting necessary. The four holes inside are ready for screws that mount the PCB to the base. The base will be 3D printed with a basic plastic material. It does not have to be anything more as plastic will last a while in basic outdoors conditions. The lid will be laser cut from clear acrylic. It must be clear to allow light through for the light sensor. All of the smaller holes in the lid and base are used for connecting the two and including some type of material to seal the two together, whether it be an o-ring or some type of glue. The PCB layout is the same layout that was designed in Lab 8.


### Cost Analysis

Sculpteo
| 5 | 20 | 50 | 100
Base | $355.60 | $1,890.00 | $4,725.00 | $9,450.00
Lid | $14.35 | $40.00 | $92.50 | $180.00
Total | $369.95 | $1,930.00 | $4,817.50 | $9,630.00

Shapeways (not including 15% edu discount) (does not offer laser cutting, prices for 3D printing)
| 5 | 20 | 50 | 100
Base | $251.95 | $1,007.80 | $2,519.50 | $5,039.00
Lid | $78.90 | $315.60 | $789.00 | $1,578.00
Total | $330.85 | $1,323.40 | $3,308.50 | $6,617.00

Macrofab
| 5 | 20 | 50 | 100
PCB | $143.77 | $532.55 | $834.45 | $1,092.39

The above tables show prices to obtain each part from the different companies that offer 3D printing, laser cutting, and PCB printing services. For each company, I chose the most cost effective solution which involved prioritizing cost over speed. For most of the companies, it would take around 2-4 weeks to receive the components ordered. Speed is not as important of a factor when we are trying to make sure the boards are as low-priced as possible.

### Conclusion

Based on the various prices, the best and cheapest way to obtain the base + lid combo would be to use Sculpteo for the lid, Shapeways for the base, and Macrofab for the PCB. The price for Shapeways would also be reduced by taking advantage of the 15% education discount, which was not included in the above graphs. Adding this sum up, with the education discount included, the total for 100 light sensors would be $5,555.54. The price per unit would then be $55.55.

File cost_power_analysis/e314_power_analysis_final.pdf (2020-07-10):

Power Analysis

Background:

Our light monitoring system is composed of the STM32L432KC (STM) microcontroller and the TSL237 light sensor. The system is designed to take light samples every 15 minutes for 12 hours a day, with each sample taking up to 15 seconds. When the system is taking a light sample, it will be in one of three running modes, and while it is idle, the system will be in one of seven low-power modes. The following graphs show the power consumption of different combinations of run and low-power modes, generated by CubeMX. We are trying to determine the pair of run and low-power modes that will yield the best battery life with a CR2032 battery.

When testing each of the running modes, we made sure to use the highest CPU frequency that each mode can handle. We enabled the ADC, RTC, UART, a timer, and several GPIO peripherals. Additionally, for each run mode, we gave an additional 2 mA of consumption to account for the light sensor. For the low power modes, we enabled only the RTC and the UART if it is supported. In each plot, we let the system run for 15 seconds and then enter low-power mode for 900 seconds (15 minutes).

Analysis

RUN (Range 1)

The following figures 1-6 show the power consumption of the RUN power mode at Range 1 with multiple low-power modes. In each case, the CPU is running at a max of 80 MHz. However, the faster clock speed means that the STM draws more power. The code is running from FLASH, so that also takes extra current to maintain. Figure 6 shows the longest battery life approximation with STANDBY as the low-power mode at 1 month, 16 days and 15 hours. The other run modes last much longer across the board. Performance-wise, we receive little benefit from the extra clock speed because our system does not compute much, it just stores data. Thus, it does not seem worth sacrificing battery life for the extra speed of RUN at Range 1.


Figure 1: RUN (Range 1) with SLEEP

SLEEP consumes the most current out of all the low-power modes at 120 uA, but as a result the wake-up time is the fastest at 6 clock cycles. The LPUART and RTC can still be enabled, and SRAM is retained.


Figure 2: RUN (Range 1) with STOP 0

STOP 0 consumes slightly less current than SLEEP at 111 uA, and its wakeup time is slower at 0.7 us. The LPUART and RTC can still be enabled, and SRAM is retained. Battery life is improved by about 10 hours compared to using SLEEP.


Figure 3: RUN (Range 1) with STOP 1

STOP 1 consumes even less current than STOP 0 at 5.3 uA, and its wakeup time is 4 us. The LPUART and RTC can still be enabled, and SRAM is retained. The difference between STOP 0 and STOP 1 in terms of power consumption is significant though, giving us an extra 15.5 days before the battery dies.


Figure 4: RUN (Range 1) with STOP 2

STOP 2 consumes less current than STOP 1 at 1.8 uA, and its wakeup time is 5 us. The LPUART and RTC can still be enabled, and SRAM is retained. STOP 2 gives us an additional 19 hours of battery life over STOP 1.


Figure 5: RUN (Range 1) with STANDBY + 32KB SRAM

STANDBY with SRAM consumes even less current than STOP 2 at 582 nA, but its wakeup time is more than doubled at 14 us. The LPUART can no longer stay enabled, but RTC is still active and SRAM is retained. This means if we want to communicate with the device over UART, we must wait 15 minutes before the system is back in the run mode. For the effort, we only gain 6 hours of extra battery life compared to STOP 2.


Figure 6: RUN (Range 1) with STANDBY

STANDBY without SRAM consumes less current than before at 404 nA, but its wakeup time is still at 14 us. The LPUART can no longer stay enabled and SRAM is not retained, but RTC is still active. This means if we want to communicate with the device over UART, we must wait 15 minutes before the system is back in the run mode. This only gains us 2 hours of battery life.

RUN (Range 2)

The following figures 7-12 show the power consumption of the RUN power mode at Range 2 with different low-power modes. Range 2 is different from Range 1 because the CPU can only run at a max of 26 MHz, and the code is executing from SRAM instead of FLASH. If the low-power mode does not retain SRAM, we will need to move our code to FLASH before entering. However, the benefit to the battery life for these drawbacks is significant. Figure 12 shows the longest battery life approximation with STANDBY as the low-power mode at 3 months, 25 days and 18 hours.


Figure 7: RUN (Range 2) with SLEEP

As mentioned before, SLEEP consumes the most current out of all the low-power modes at a little over 111 uA, but as a result the wake-up time is the fastest at 6 clock cycles. The LPUART and RTC can still be enabled, and SRAM is retained.


Figure 8: RUN (Range 2) with STOP 0

STOP 0 consumes roughly the same current as SLEEP at 111 uA, and its wakeup time is slower at 0.7 us. The LPUART and RTC can still be enabled, and SRAM is retained. Battery life is improved by about 1 hour compared to using SLEEP.


Figure 9: RUN (Range 2) with STOP 1

As mentioned before, STOP 1 consumes much less current than STOP 0 at 5.3 uA, and its wakeup time is 4 us. The LPUART and RTC can still be enabled, and SRAM is retained. The difference between STOP 0 and STOP 1 in terms of power consumption is significant though, giving us an extra 2 months before the battery dies.


Figure 10: RUN (Range 2) with STOP 2

As mentioned before, STOP 2 consumes less current than STOP 1 at 1.8 uA, and its wakeup time is 5 us. The LPUART and RTC can still be enabled, and SRAM is retained. STOP 2 gives us an additional 4 days and 16 hours of battery life over STOP 1.


Figure 11: RUN (Range 2) with STANDBY + 32KB SRAM

As mentioned before, STANDBY with SRAM consumes even less current than STOP 2 at 582 nA, but its wakeup time is more than doubled at 14 us. The LPUART can no longer stay enabled, but RTC is still active and SRAM is retained. This means if we want to communicate with the device over UART, we must wait 15 minutes before the system is back in the run mode. For the effort, we gain 1 day and 18 hours of extra battery life compared to STOP 2.


Figure 12: RUN (Range 2) with STANDBY

As mentioned before, STANDBY without SRAM consumes less current than before at 404 nA, but its wakeup time is still at 14 us. The LPUART can no longer stay enabled and SRAM is not retained, but RTC is still active. This means if we want to communicate with the device over UART, we must wait 15 minutes before the system is back in the run mode. Additionally, upon entering the state we must store the code in FLASH, and upon exiting we must load the code from FLASH into SRAM. This only gains us 6 hours of battery life.

LPRUN

The following figures 13-17 show the power consumption of the LPRUN power mode with different low-power modes. LPRUN has unique access to LPSLEEP, but it does not support STOP 2. The CPU can only run at a max of 2 MHz. The slower clock speed means that the STM conserves a lot of power. The code is running from FLASH, so that also takes extra current to maintain. However, the benefit to the battery life for this drawback is significant. Figure 17 shows the longest battery life approximation with STANDBY as the low-power mode at 7 months, 24 days and 15 hours. The issue will be whether 2 MHz is enough to perform all our operations in a reasonable amount of time.


Figure 13: LPRUN with LPSLEEP

LPSLEEP can only be used with LPRUN and consumes very little current at just 72 uA. It also wakes up from sleep very quickly at just 6 clock cycles. The LPUART and RTC can still be enabled, and SRAM is retained.


Figure 14: LPRUN with STOP 0

STOP 0 is surprisingly worse than LPSLEEP when combined with LPRUN, consuming 111 uA of current and with a slower wakeup time of 0.7 us. The LPUART and RTC can still be enabled, and SRAM is retained. Battery life is worse than LPSLEEP by 22 days; it is unlikely we would choose STOP 0 over LPSLEEP when using LPRUN.


Figure 15: LPRUN with STOP 1

As mentioned before, STOP 1 consumes much less current than STOP 0 at 5.3 uA, and its wakeup time is 4 us. The LPUART and RTC can still be enabled, and SRAM is retained. The difference between STOP 0 and STOP 1 in terms of power consumption is significant though, giving us almost 5 extra months before the battery dies.


Figure 16: LPRUN with STANDBY + 32KB SRAM

STANDBY with SRAM consumes even less current than STOP 1 at 582 nA, but its wakeup time is more than tripled at 14 us. The LPUART can no longer stay enabled, but RTC is still active and SRAM is retained. This means if we want to communicate with the device over UART, we must wait 15 minutes before the system is back in the run mode. For the effort, we gain about 24 days of extra battery life compared to STOP 1.


Figure 17: LPRUN with STANDBY

As mentioned before, STANDBY without SRAM consumes less current than before at 404 nA, but its wakeup time is still at 14 us. The LPUART can no longer stay enabled and SRAM is not retained, but RTC is still active. This means if we want to communicate with the device over UART, we must wait 15 minutes before the system is back in the run mode. This only gains us 1 day and 1 hour of battery life.

Conclusion

For the run mode, RUN at Range 2 provides a reasonable clock speed for decent battery performance. LPRUN would provide much better battery performance, but 2 MHz may be too slow for calculations and will make the response over UART slow. For the low-power mode, STOP 2 seems ideal because it provides the best battery performance while still allowing us to communicate over UART and retain the state of SRAM. STANDBY options would give us better battery life, but it disables UART, meaning that we only have a small 15 second window to connect with the system in the RUN state. As figure 10 states, the RUN (Range 2) coupled with STOP 2 gives 3 months, 23 days and 18 hours of battery life. Moreover, if we do not need the full 26 MHz for our computations, we could lower the clock rate to achieve even better battery life.

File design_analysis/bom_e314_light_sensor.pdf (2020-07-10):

Id | Designator | Package | Quantity | Designation
1 | U1 | TG-3541CE | 1 | TG-3541CE
2 | TP3,TP2,TP1 | TestPoint_Pad_D1.5mm | 3 | TestPoint
3 | R2,R1 | R_0603_1608Metric_Pad1.05x0.95mm_HandSolder | 2 | 200
4 | JP1 | SolderJumper-3_P1.3mm_Open_RoundedPad1.0x1.5mm | 1 | Jumper_3_Open
5 | J2 | JST_XH_B3B-XH-AM_1x03_P2.50mm_Vertical | 1 | Conn_01x03
6 | J1 | JST_XH_B4B-XH-AM_1x04_P2.50mm_Vertical | 1 | Conn_01x04_Male
7 | IC1 | | 1 | TSL237S-LF
8 | H4,H3,H2,H1 | MountingHole_2.2mm_M2_Pad_Via | 4 | MountingHole
9 | C2,C4 | C_0603_1608Metric_Pad1.05x0.95mm_HandSolder | 2 | 1uF
10 | C1,C3 | C_0603_1608Metric_Pad1.05x0.95mm_HandSolder | 2 | 0.1uF
11 | BT1 | BatteryHolder_Keystone_1060_1x2032 | 1 | Battery_Cell
12 | U3 | QFN-32-1EP_5x5mm_P0.5mm_EP3.45x3.45mm | 1 | STM32L432KCUx
13 | U2 | ftsh_14p_connector | 1 | STDC14
Mfr Part Number | Component Description | Reference Designator(s) | Distributor | Unit Cost | Extended Cost | Link
TG-3541CE 32.7680KXA3 | XTAL OSC TCXO 32.7680KHZ CMOS | U1 | Digikey | $2.15600 | $2.15600 | Link (https://www.digikey.com/product-detail/en/epson/TG-3541CE-32.7680KXA3/SER4421CT-ND/10239844)
RCU-0C | PC TEST POINT NATURAL | TP3,TP2,TP1 | Digikey | $0.10982 | $0.32946 | Link (https://www.digikey.com/product-detail/en/te-connectivity-amp-connectors/RCU-0C/A106145DKR-ND/3477924)
SG73G1JTTD2000D (https://www.mouser.com/ProductDetail/KOA-Speer/SG73G1JTTD2000D) | Thick Film Resistors - SMD 200 ohm 0.5% 0.33W AEC-Q200 | R2,R1 | Mouser | $0.09000 | $0.18000 | Link (https://www.mouser.com/Passive-Components/Resistors/SMD-Resistors-Chip-Resistors/_/N-7h7yu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)
B3B-XH-A(LF)(SN) | CONN HEADER VERT 3POS 2.5MM | J2 | DigiKey | $0.08075 | $0.08075 | Link (https://www.digikey.com/product-detail/en/jst-sales-america-inc/B3B-XH-A-LF-SN/455-2248-ND/1651046)
B4B-XH-A(LF)(SN) | CONN HEADER VERT 4POS 2.5MM | J1 | DigiKey | $0.09333 | $0.09333 | Link (https://www.digikey.com/product-detail/en/jst-sales-america-inc/B4B-XH-A-LF-SN/455-2249-ND/1651047)
TSL237S-LF | SENSOR OPT 635NM AMB SIDELOOKER | IC1 | DigiKey | $1.92850 | $1.92850 | Link (https://www.digikey.com/product-detail/en/ams/TSL237S-LF/TSL237-S-LF-ND/3095041)
C0603C105K8RACTU | CAP CER 1UF 10V X7R 0603 | C2,C4 | DigiKey | $0.01164 | $0.02328 | Link (https://www.digikey.com/product-detail/en/kemet/C0603C105K8RACTU/399-11133-2-ND/2199790)
C0603C104K8RACTU | CAP CER 0.1UF 10V X7R 0603 | C1,C3 | DigiKey | $0.02683 | $0.05366 | Link (https://www.digikey.com/product-detail/en/kemet/C0603C104K8RACTU/399-1095-1-ND/411370)
36-1060CT-ND | BATTERY HOLDER COIN 20MM SMD | BT1 | DigiKey | $1.02744 | $1.02744 | Link (https://www.digikey.com/products/en?keywords=36-1060CT-ND)
STM32L432KCU6 | ARM Microcontrollers - MCU 16/32-BITS MICROS | U3 | Mouser | $2.94000 | $2.94000 | Link (https://www.mouser.com/ProductDetail/STMicroelectronics/STM32L432KCU6)
FTSH-107-01-L-DV-K-P-TR | CONN HEADER SMD 14POS 1.27MM | U2 | DigiKey | $3.85000 | $3.85000 | Link (https://www.digikey.com/products/en/connectors-interconnects/rectangular-connectors-headers-male-pins/314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)

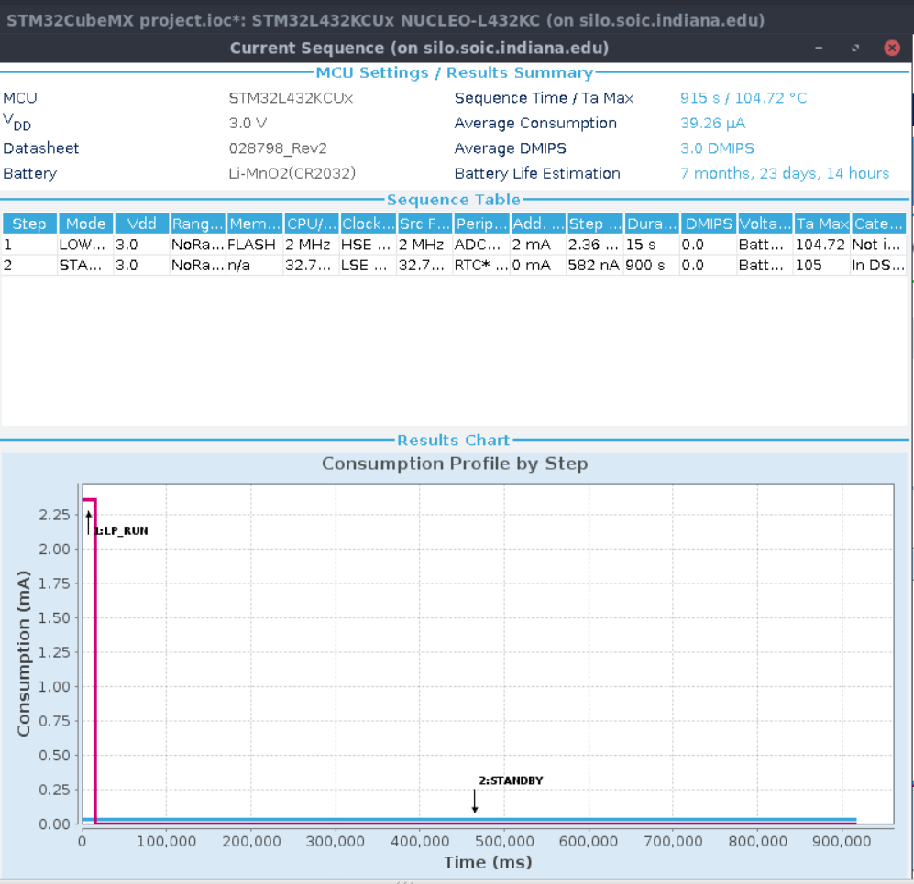
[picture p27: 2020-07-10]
cost_power_analysis/screenshots/lprun_standby32.png

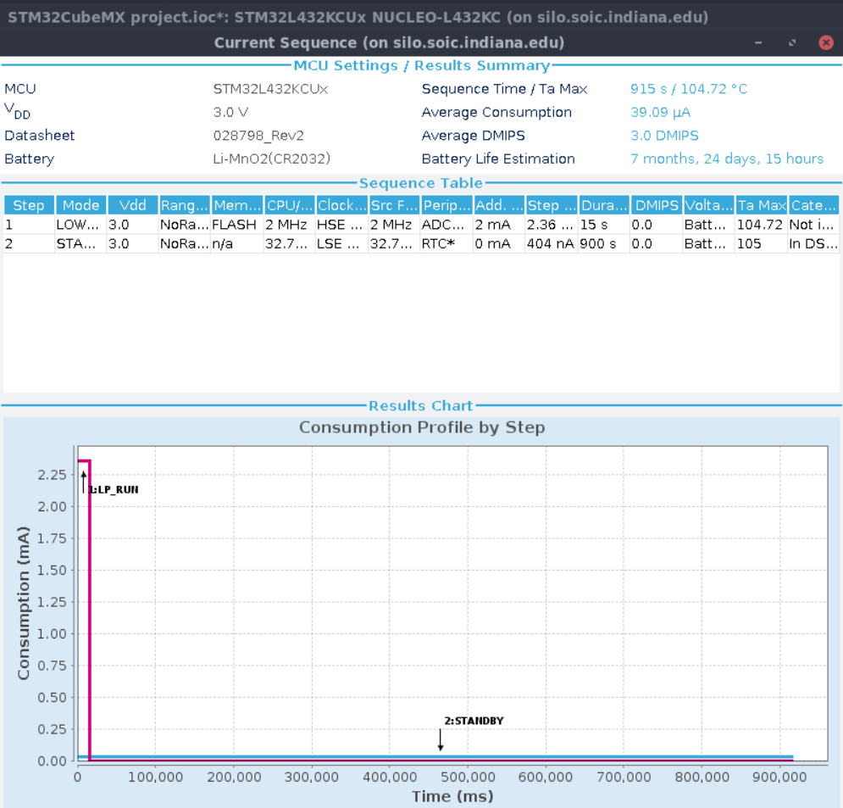
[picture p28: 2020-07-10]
cost_power_analysis/screenshots/lprun_standby.png

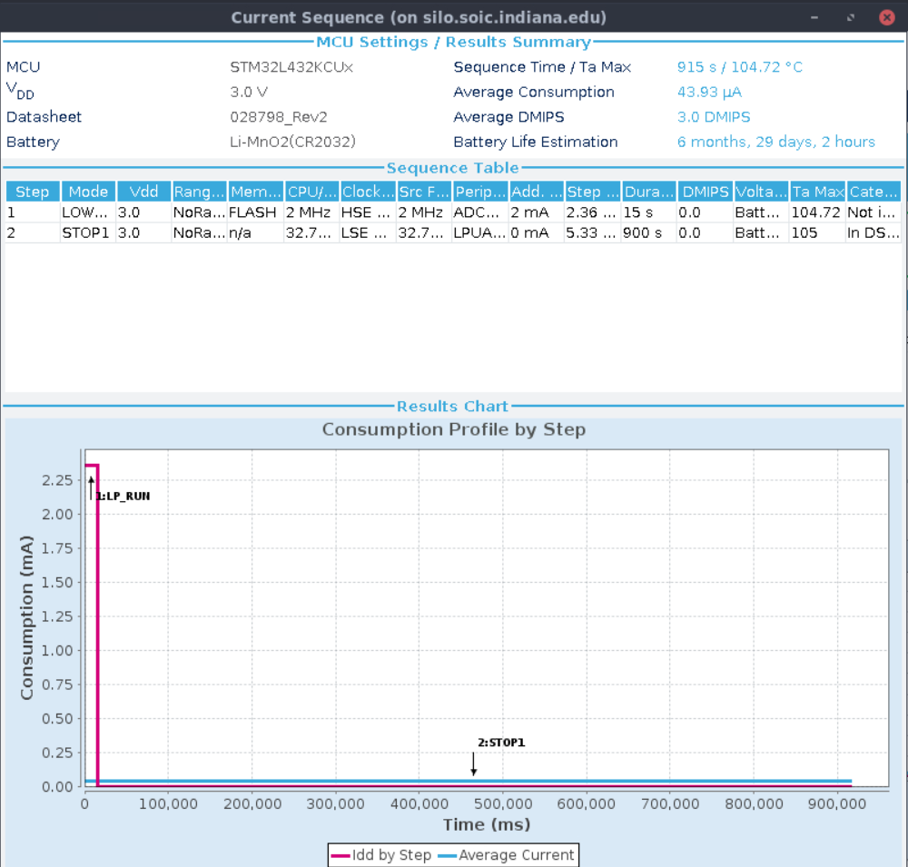
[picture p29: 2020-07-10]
cost_power_analysis/screenshots/lprun_stop1.png

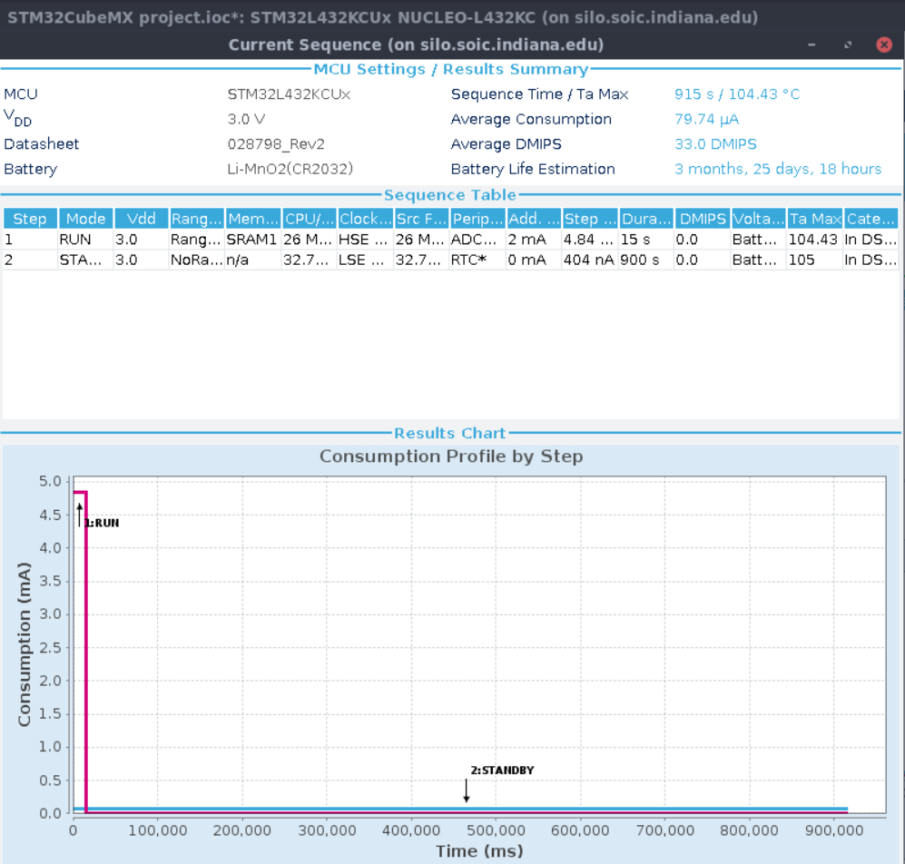
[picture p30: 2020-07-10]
cost_power_analysis/screenshots/run2_standby.png

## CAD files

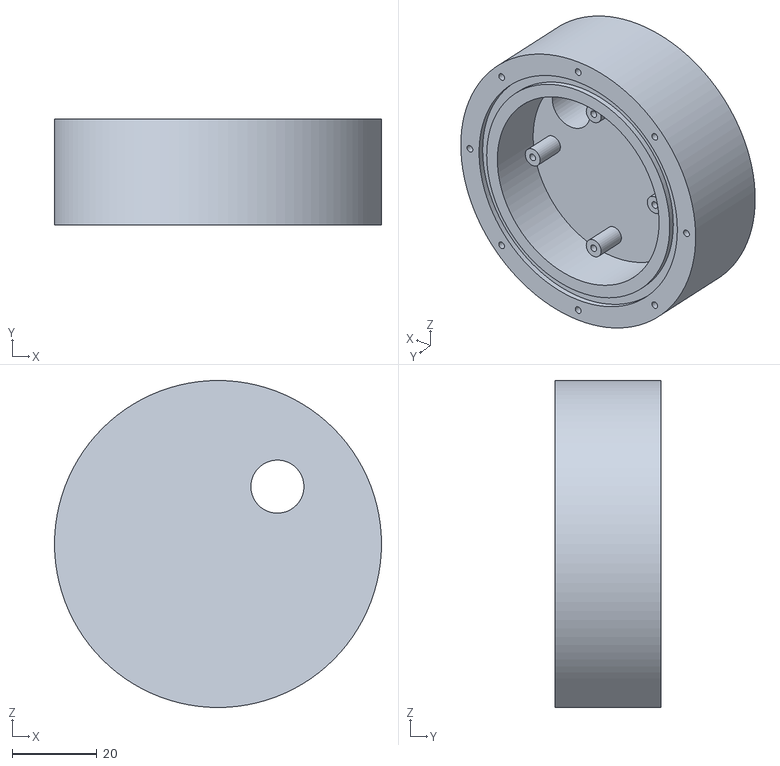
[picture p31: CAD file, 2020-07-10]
enclosure/Base/e314 base v4.stl
77.0 x 25.0 x 77.0

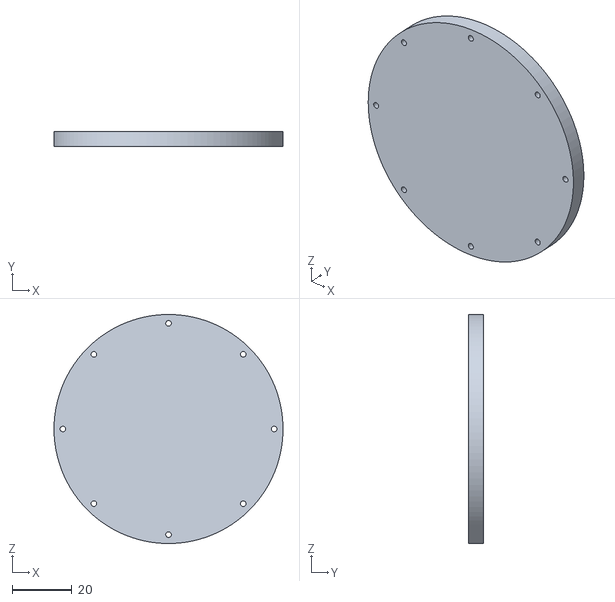
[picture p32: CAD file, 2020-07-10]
enclosure/Lid/e314 lid v1.stl
77.0 x 5.00 x 77.0

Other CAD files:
enclosure/Base/e314 base v4.f3d
enclosure/Lid/e314 lid v1.dxf
enclosure/Lid/e314 lid v1.f3d

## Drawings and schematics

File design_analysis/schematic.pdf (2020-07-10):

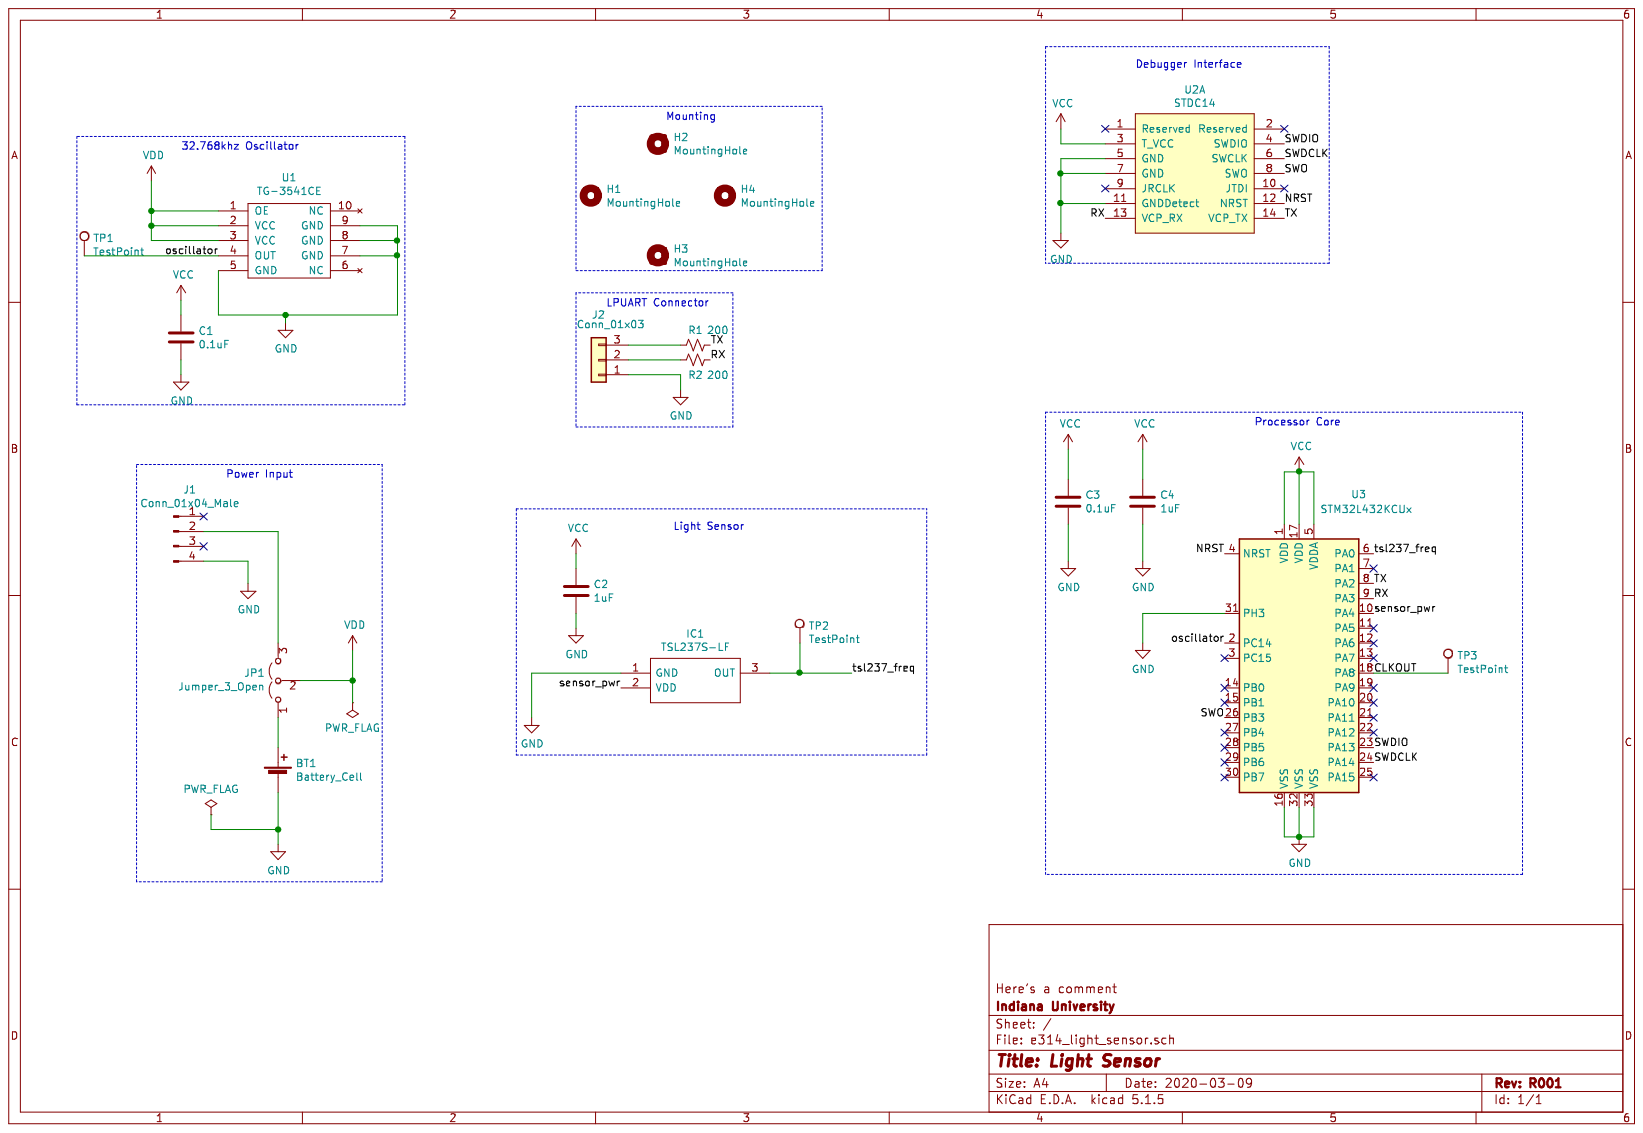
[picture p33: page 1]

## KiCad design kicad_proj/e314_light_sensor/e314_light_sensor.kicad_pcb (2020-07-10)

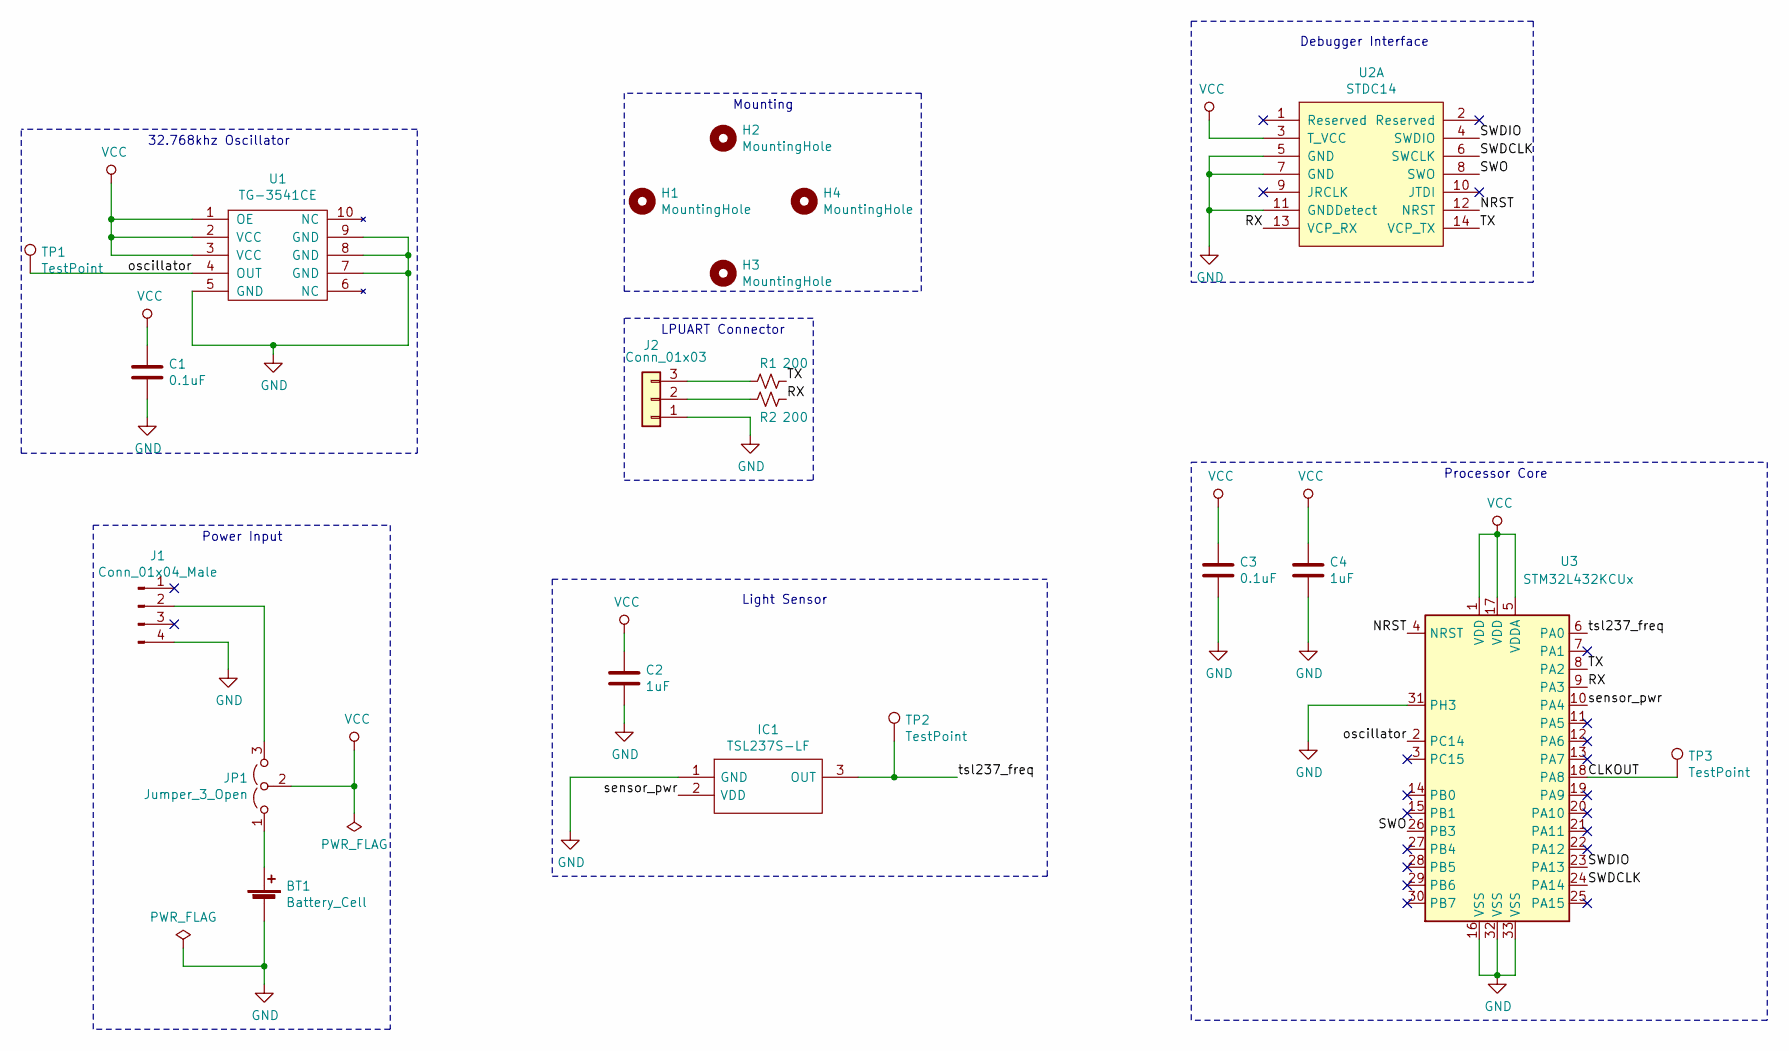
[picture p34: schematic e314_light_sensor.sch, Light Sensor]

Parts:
BT1: Battery_Cell; BatteryHolder_Keystone_1060_1x2032
C1, C3: 0.1uF; C_0603_1608Metric_Pad1.05x0.95mm_HandSolder
C2, C4: 1uF; C_0603_1608Metric_Pad1.05x0.95mm_HandSolder
H1, H2, H3, H4: MountingHole; MountingHole_2.2mm_M2_Pad_Via
IC1: TSL237S-LF; Mouser Part Number 856-TSL237S-LF
J1: Conn_01x04_Male; JST_XH_B4B-XH-AM_1x04_P2.50mm_Vertical
J2: Conn_01x03; JST_XH_B3B-XH-AM_1x03_P2.50mm_Vertical
JP1: Jumper_3_Open; SolderJumper-3_P1.3mm_Open_RoundedPad1.0x1.5mm
R1, R2: 200; R_0603_1608Metric_Pad1.05x0.95mm_HandSolder
TP1, TP2, TP3: TestPoint; TestPoint_Pad_D1.5mm
U1: TG-3541CE
U2: STDC14; ftsh_14p_connector
U3: STM32L432KCUx; QFN-32-1EP_5x5mm_P0.5mm_EP3.45x3.45mm

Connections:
/CLKOUT: TP3.1, U3.18 (PA8)
/NRST: U2.12 (NRST), U3.4 (NRST)
/RX: R2.1, U2.13 (VCP_RX), U3.9 (PA3)
/SWDCLK: U2.6 (SWCLK), U3.24 (PA14)
/SWDIO: U2.4 (SWDIO), U3.23 (PA13)
/SWO: U2.8 (SWO), U3.26 (PB3)
/TX: R1.1, U2.14 (VCP_TX), U3.8 (PA2)
/oscillator: TP1.1, U1.4 (OUT), U3.2 (PC14)
/sensor_pwr: IC1.2 (VDD), U3.10 (PA4)
/tsl237_freq: IC1.3 (OUT), TP2.1, U3.6 (PA0)
GND: BT1.2 (-), C1.2, C2.2, C3.2, C4.2, IC1.1 (GND), J1.4, J2.1, U1.5 (GND), U1.7 (GND), U1.8 (GND), U1.9 (GND), U2.5 (GND), U2.7 (GND), U2.11 (GNDDetect), U3.16 (VSS), U3.31 (PH3), U3.32 (VSS), U3.33 (VSS)
unnamed: BT1.1 (+), JP1.1 (A)
unnamed: J1.2, JP1.3 (B)
unnamed: J2.2, R2.2
unnamed: J2.3, R1.2
VCC: C1.1, C2.1, C3.1, C4.1, JP1.2 (C), U1.1 (OE), U1.2 (VCC), U1.3 (VCC), U2.3 (T_VCC), U3.1 (VDD), U3.5 (VDDA), U3.17 (VDD)

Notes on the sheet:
Debugger Interface
Processor Core
32.768khz Oscillator
Power Input
Light Sensor
LPUART Connector
Mounting

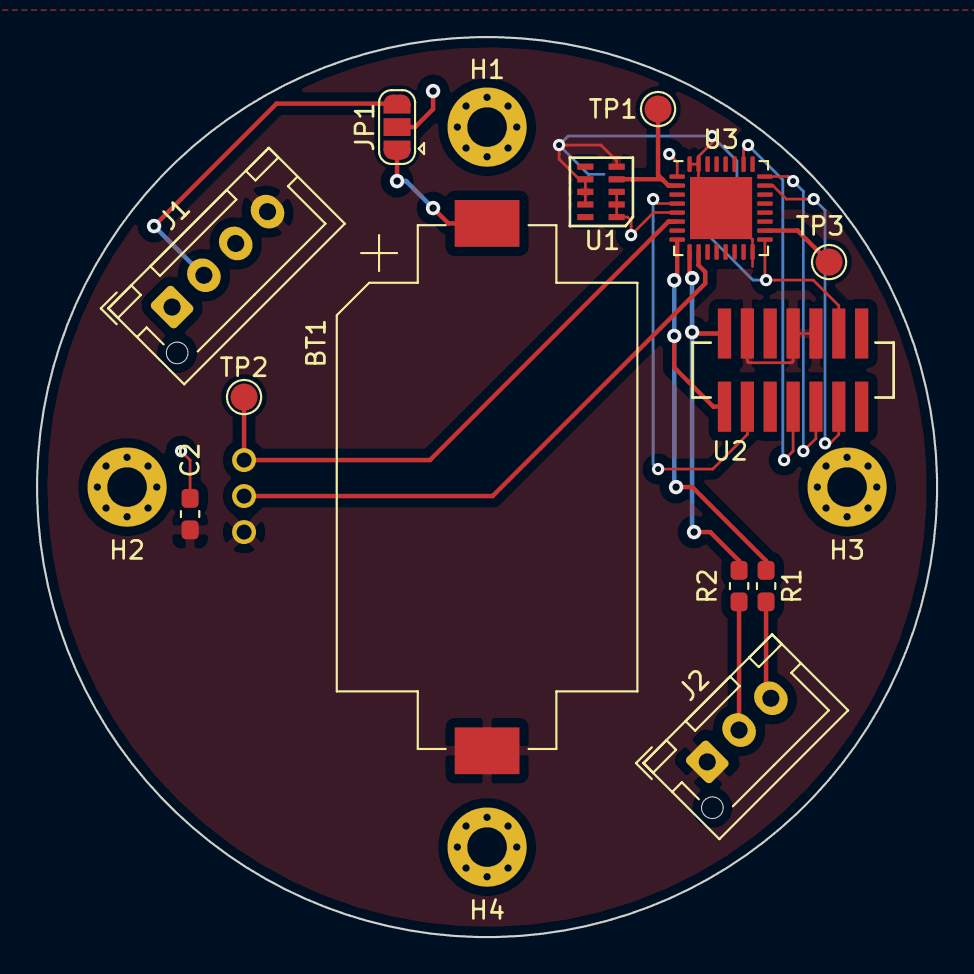
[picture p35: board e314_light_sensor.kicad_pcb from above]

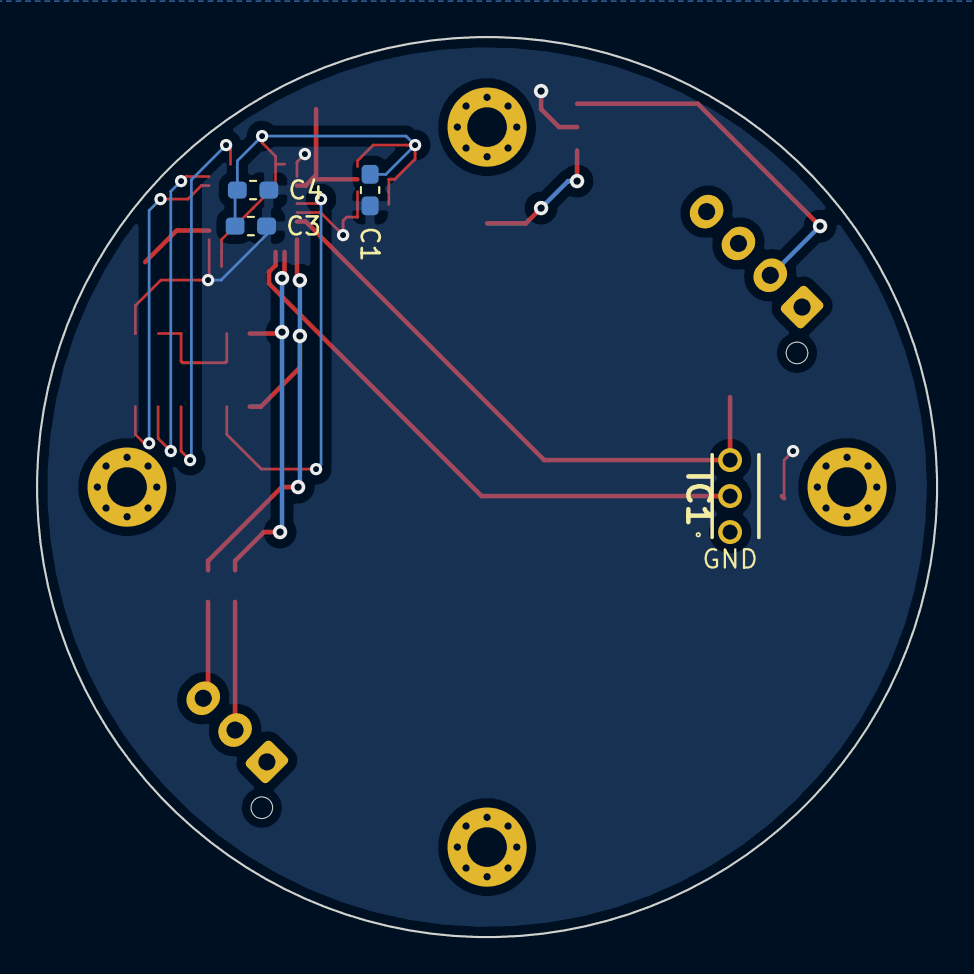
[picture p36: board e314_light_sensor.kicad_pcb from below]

Board: 2 copper layers, 50.0 x 50.0 mm, 21 parts (4 on the bottom side), 16 nets.

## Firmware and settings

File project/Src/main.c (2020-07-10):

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

/* Includes ------------------------------------------------------------------*/
#include "main.h"

/* USER CODE BEGIN Includes */
#include <stdio.h>
#include "retarget.h"
#include <string.h>
#include <stdlib.h>
#include "stm32l4xx_ll_usart.h"
#include "command.h"
#include "buffer.h"
#include "rtc.h"
#include "sensor.h"
#include "log.h"
/* USER CODE END Includes */

ADC_HandleTypeDef hadc1;
RTC_HandleTypeDef hrtc;
TIM_HandleTypeDef htim2;
DMA_HandleTypeDef hdma_tim2_ch1;
UART_HandleTypeDef huart2;

void SystemClock_Config(void);
static void MX_GPIO_Init(void);
static void MX_USART2_UART_Init(void);
static void MX_RTC_Init(void);
static void MX_ADC1_Init(void);
static void MX_DMA_Init(void);
static void MX_TIM2_Init(void);
/**
  * @brief  The application entry point.
  * @retval int
  */
int main(void)
{
  

  /* MCU Configuration--------------------------------------------------------*/

  /* Reset of all peripherals, Initializes the Flash interface and the Systick. */
  HAL_Init();

  /* Configure the system clock */
  SystemClock_Config();

  /* Initialize all configured peripherals */
  MX_GPIO_Init();
  MX_USART2_UART_Init();
  MX_RTC_Init();
  MX_ADC1_Init();
  MX_DMA_Init();
  MX_TIM2_Init();
  /* USER CODE BEGIN 2 */
  RetargetInit(&huart2);
  //sends local RTC handler variable to rtc.c file scope
  RetargetRTC(&hrtc);
  
  // if necessary to erase flash, uncomment
  //flash_erase();
  
  if(flash_write_init()) {
    printf("Flash initialization failed\r\n");
    while(1);
  }
  //calibrates ADC
  while (HAL_ADCEx_Calibration_Start(&hadc1,ADC_SINGLE_ENDED) != HAL_OK); 
  

  log_entry("start");
  printf("Welcome to Nucleo\r\n");
  printf("Type 'help' to see available commands\r\n");

  HAL_GPIO_WritePin(LD3_GPIO_Port, LD3_Pin, GPIO_PIN_RESET);

  terminal_line();
  /* USER CODE END 2 */

  /* Infinite loop */
  /* USER CODE BEGIN WHILE */
  while (1)
  {
    /* USER CODE END WHILE */

    /* USER CODE BEGIN 3 */
    buf_process();
    alarm_process();
  }
  /* USER CODE END 3 */
}

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


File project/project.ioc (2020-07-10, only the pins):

Mcu.UserName=STM32L432KCUx
PA0.GPIO_Label=MCO [High speed clock in]
PA0.Signal=RCC_CK_IN
PA2.GPIO_Label=VCP_TX
PA2.Signal=USART2_TX
PA5.Signal=S_TIM2_CH1

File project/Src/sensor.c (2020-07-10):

#include <_ansi.h>
#include <_syslist.h>
#include <errno.h>
#include <sys/time.h>
#include <sys/times.h>
#include <limits.h>
#include <signal.h>
#include <stdint.h>
#include <stdio.h>
#include "retarget.h"
#include "main.h"
#include <string.h>
#include <stdlib.h>

#include "sensor.h"

extern TIM_HandleTypeDef htim2;
extern ADC_HandleTypeDef hadc1;

volatile uint8_t captureDone = 0;

float calculate_freq() {
  uint32_t captures[2];
  uint32_t diffCapture = 0;
  float freq = 0;

  HAL_TIM_IC_Start_DMA(&htim2, TIM_CHANNEL_1, (uint32_t*) captures, 2);

  while(1){
    if(captureDone){
      if(captures[1] >= captures[0]) {
        diffCapture = captures[1] - captures[0];
      }
      else {
        diffCapture = (htim2.Instance->ARR - captures[0]) + captures[1];
      }

      freq = HAL_RCC_GetHCLKFreq() / (htim2.Instance->PSC + 1);
      freq = (float) freq / diffCapture;

      captureDone = 0;
      break;
    }
  }
  
  return freq;
}

uint32_t calculate_period() {
  uint32_t captures[2];
  uint32_t diffCapture = 0;

  HAL_TIM_IC_Start_DMA(&htim2, TIM_CHANNEL_1, (uint32_t*) captures, 2);

  while(1){
    if(captureDone){
      if(captures[1] >= captures[0]) {
        diffCapture = captures[1] - captures[0];
      }
      else {
        diffCapture = (htim2.Instance->ARR - captures[0]) + captures[1];
      }
      captureDone = 0;
      break;
    }
  }
  
  return diffCapture;
}

void HAL_TIM_IC_CaptureCallback(TIM_HandleTypeDef *htim) {
  if (htim->Channel == HAL_TIM_ACTIVE_CHANNEL_1) {
    captureDone = 1;
  }
}

uint32_t read_temp(void) {
  static uint32_t first_time_up = 1;
  static ADC_ChannelConfTypeDef sConfig = {0};
  uint32_t rawTemp;
  uint32_t vref;
  uint32_t temp;
    
  if (first_time_up) {
    sConfig.Channel = ADC_CHANNEL_TEMPSENSOR;
    sConfig.Rank = ADC_REGULAR_RANK_1;
    sConfig.SamplingTime = ADC_SAMPLETIME_47CYCLES_5;
    sConfig.SingleDiff = ADC_SINGLE_ENDED;
    sConfig.OffsetNumber = ADC_OFFSET_NONE;
    sConfig.Offset = 0;
    first_time_up = 0;
  }
  sConfig.Rank = ADC_REGULAR_RANK_1;
  if (HAL_ADC_ConfigChannel(&hadc1, &sConfig) != HAL_OK) {
      Error_Handler();
  }
  HAL_ADC_Start(&hadc1); 
  HAL_ADC_PollForConversion(&hadc1, HAL_MAX_DELAY);
  rawTemp = HAL_ADC_GetValue(&hadc1);
  HAL_ADC_Stop(&hadc1);
  /* sConfig.Rank = ADC_REGULAR_RANK_2; */
  /* if (HAL_ADC_ConfigChannel(&hadc1, &sConfig) != HAL_OK) { */
  /*     Error_Handler(); */
  /* } */
  vref = read_vrefint();
  temp = (__HAL_ADC_CALC_TEMPERATURE(vref,
                                     rawTemp,
                                     ADC_RESOLUTION_12B));
  return temp;
}

uint32_t read_vrefint(void) {
  static uint32_t first_time_up = 1;
  static ADC_ChannelConfTypeDef sConfig = {0};
  uint32_t rawVintref;

  if (first_time_up) {
    sConfig.Channel = ADC_CHANNEL_VREFINT;
    sConfig.Rank = ADC_REGULAR_RANK_1;
    sConfig.SamplingTime = ADC_SAMPLETIME_47CYCLES_5;
    sConfig.SingleDiff = ADC_SINGLE_ENDED;
    sConfig.OffsetNumber = ADC_OFFSET_NONE;
    sConfig.Offset = 0;
    first_time_up = 0;
  }
  sConfig.Rank = ADC_REGULAR_RANK_1;
  if (HAL_ADC_ConfigChannel(&hadc1, &sConfig) != HAL_OK) {
      Error_Handler();
  }
  HAL_ADC_Start(&hadc1); 
  HAL_ADC_PollForConversion(&hadc1, HAL_MAX_DELAY);
  rawVintref = HAL_ADC_GetValue(&hadc1);
  HAL_ADC_Stop(&hadc1);
  sConfig.Rank = ADC_REGULAR_RANK_2;
  if (HAL_ADC_ConfigChannel(&hadc1, &sConfig) != HAL_OK) {
      Error_Handler();
  }
  return(__HAL_ADC_CALC_VREFANALOG_VOLTAGE(rawVintref, ADC_RESOLUTION_12B));
}

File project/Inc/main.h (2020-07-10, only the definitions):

#define MCO_Pin GPIO_PIN_0
#define MCO_GPIO_Port GPIOA
#define VCP_TX_Pin GPIO_PIN_2
#define VCP_TX_GPIO_Port GPIOA
#define SWDIO_Pin GPIO_PIN_13
#define SWDIO_GPIO_Port GPIOA
#define SWCLK_Pin GPIO_PIN_14
#define SWCLK_GPIO_Port GPIOA
#define VCP_RX_Pin GPIO_PIN_15
#define VCP_RX_GPIO_Port GPIOA
#define LD3_Pin GPIO_PIN_3
#define LD3_GPIO_Port GPIOB

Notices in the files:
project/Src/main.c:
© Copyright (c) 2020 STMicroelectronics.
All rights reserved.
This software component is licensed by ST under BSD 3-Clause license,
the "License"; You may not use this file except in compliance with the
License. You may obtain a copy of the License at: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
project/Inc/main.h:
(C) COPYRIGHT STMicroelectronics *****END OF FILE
